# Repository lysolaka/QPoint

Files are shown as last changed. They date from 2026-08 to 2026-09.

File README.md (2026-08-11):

# QPoint

This is a medicore BJT measurement device. It does not use SMUs, negative voltages, and other fancy things. The focus of this project was to learn analog circuits and use them in something (hopefully fun).

# License

This project is licensed under the GNU General Public License v3.0 or later (at your option).

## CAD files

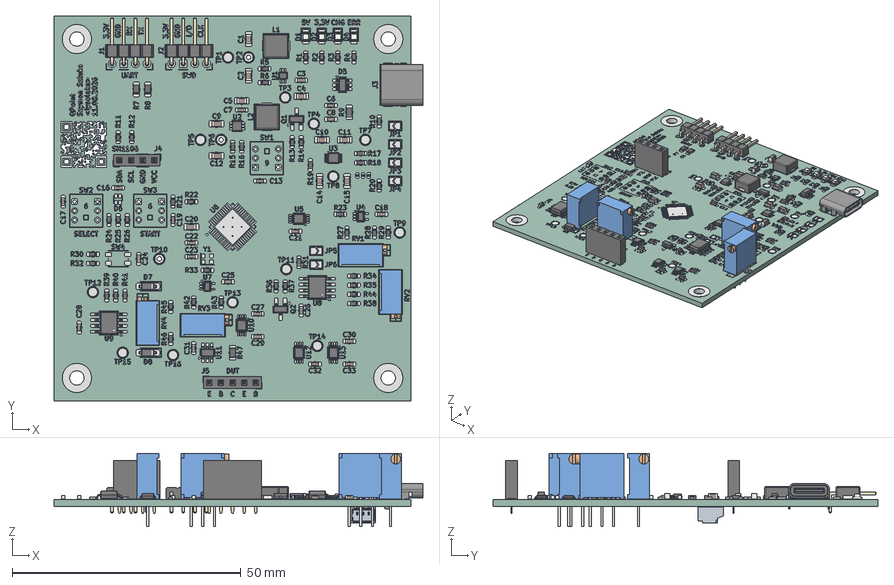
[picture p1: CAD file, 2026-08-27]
QPoint/QPointModel.step
80.6 x 84.0 x 16.1 mm
Potentiometer_Bourns_3296X_Horizontal x 4
R_0603_1608Metric x 43
C_0603_1608Metric x 22
R_0805_2012Metric x 4
USB_C_Receptacle_GCT_USB4085
D_SOD-123 x 2
PinHeader_1x04_P254mm_Horizontal x 2
C_0805_2012Metric x 11
Texas_DLH0010A_WSON-10-1EP_2.2x2mm_P0.4mm_EP0.9x1.5mm
SOT_563
PinSocket_1x05_P2.54mm_Vertical
SOT-353_SC-70-5 x 2
PinSocket_1x04_P2.54mm_Vertical
SOIC-8_3.9x4.9mm_P1.27mm x 2
VSSOP-8_2.3x2mm_P0.5mm x 4
SOT-23-6 x 2
a6ee02de-8551-11ed-a139-00155d22e2d7_part x 2
a6ee040a-8551-11ed-a139-00155d22e2d7_part x 2
a6ee048c-8551-11ed-a139-00155d22e2d7_part x 2
LED_0805_2012Metric x 4
SOT-23 x 2
WSON_6_1EP_2x2mm_P065mm_EP1x16mm
QPoint_pad
QPoint_silkscreen x 2
QPoint_PCB

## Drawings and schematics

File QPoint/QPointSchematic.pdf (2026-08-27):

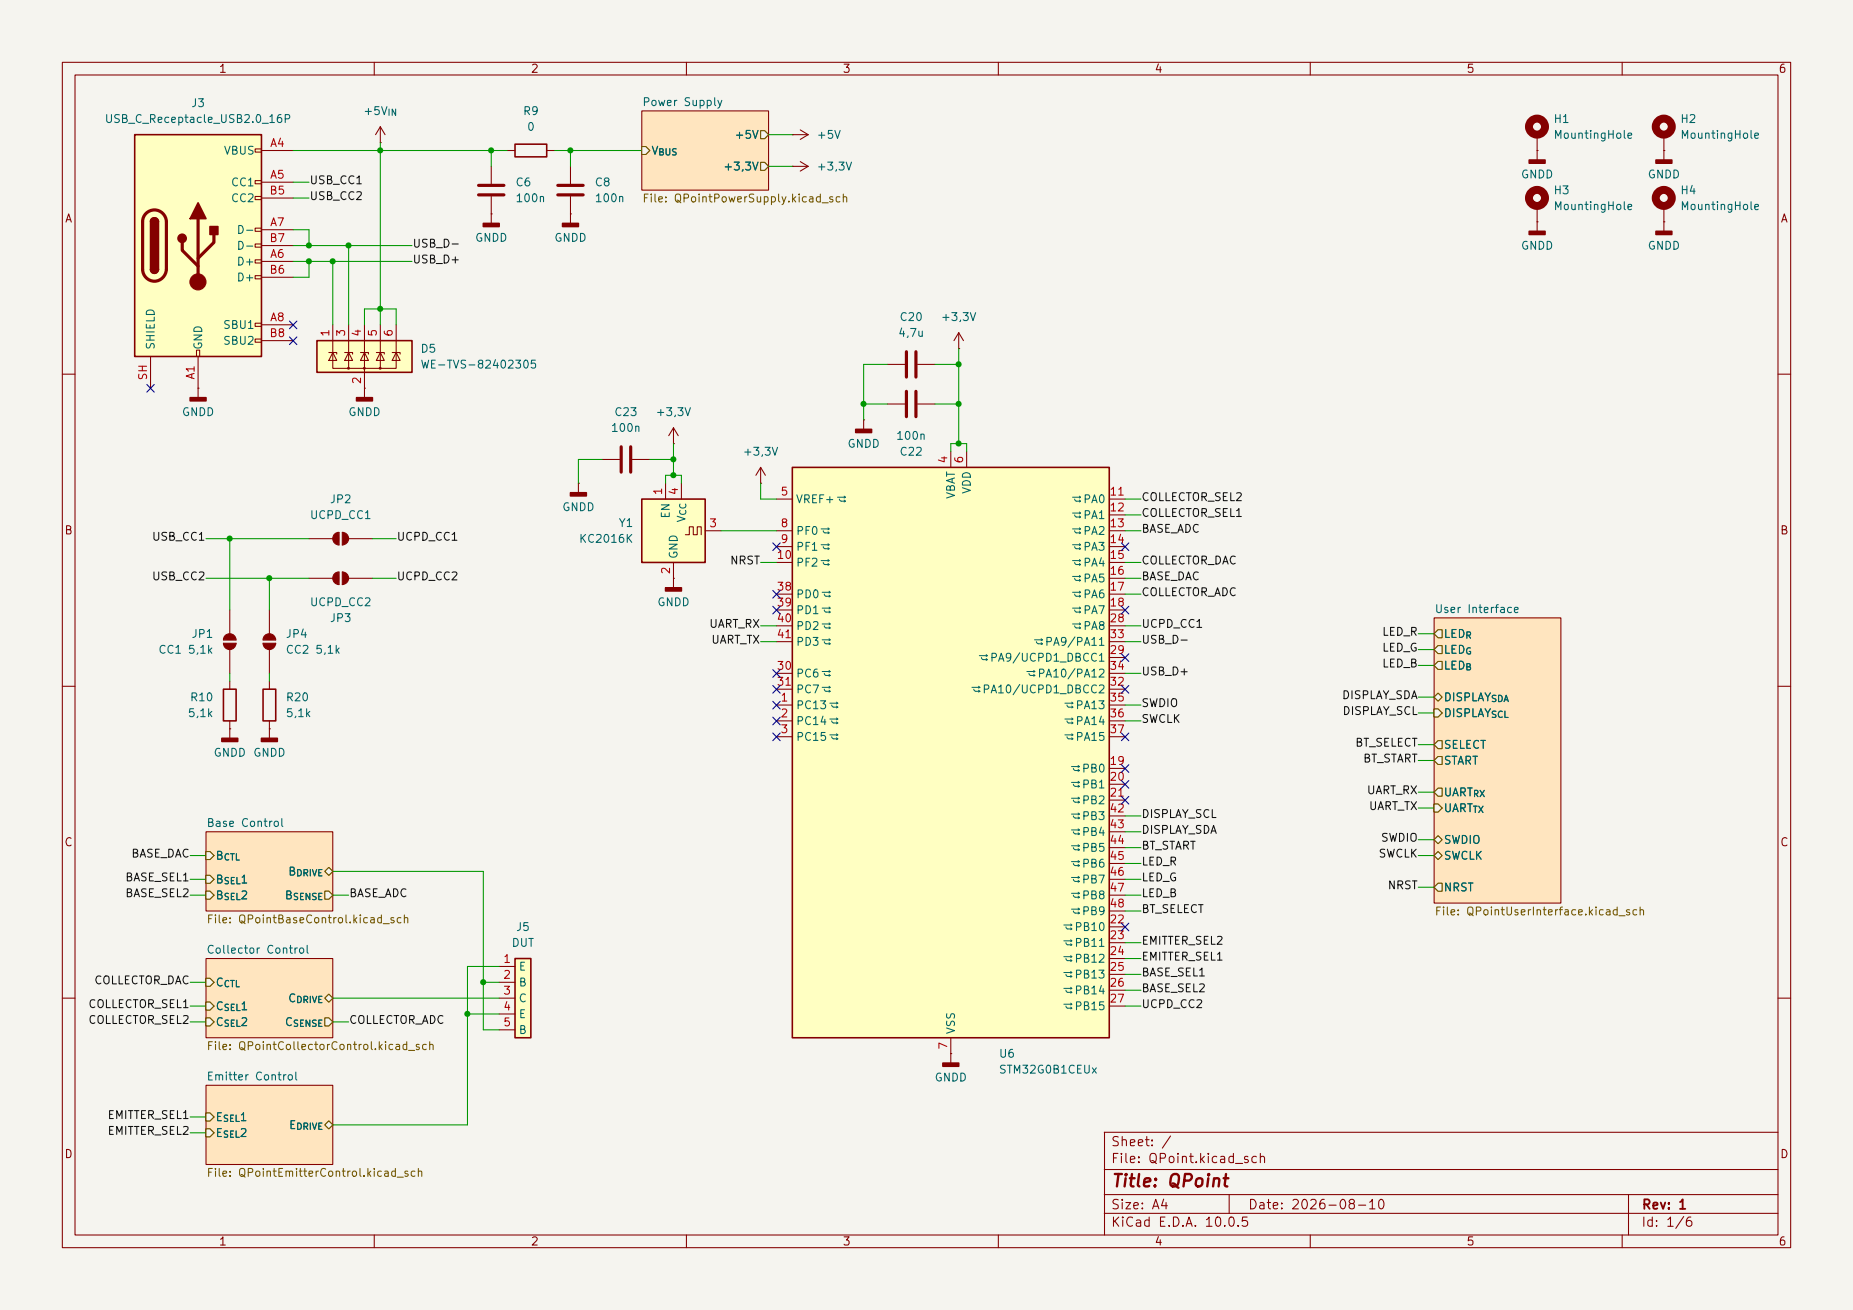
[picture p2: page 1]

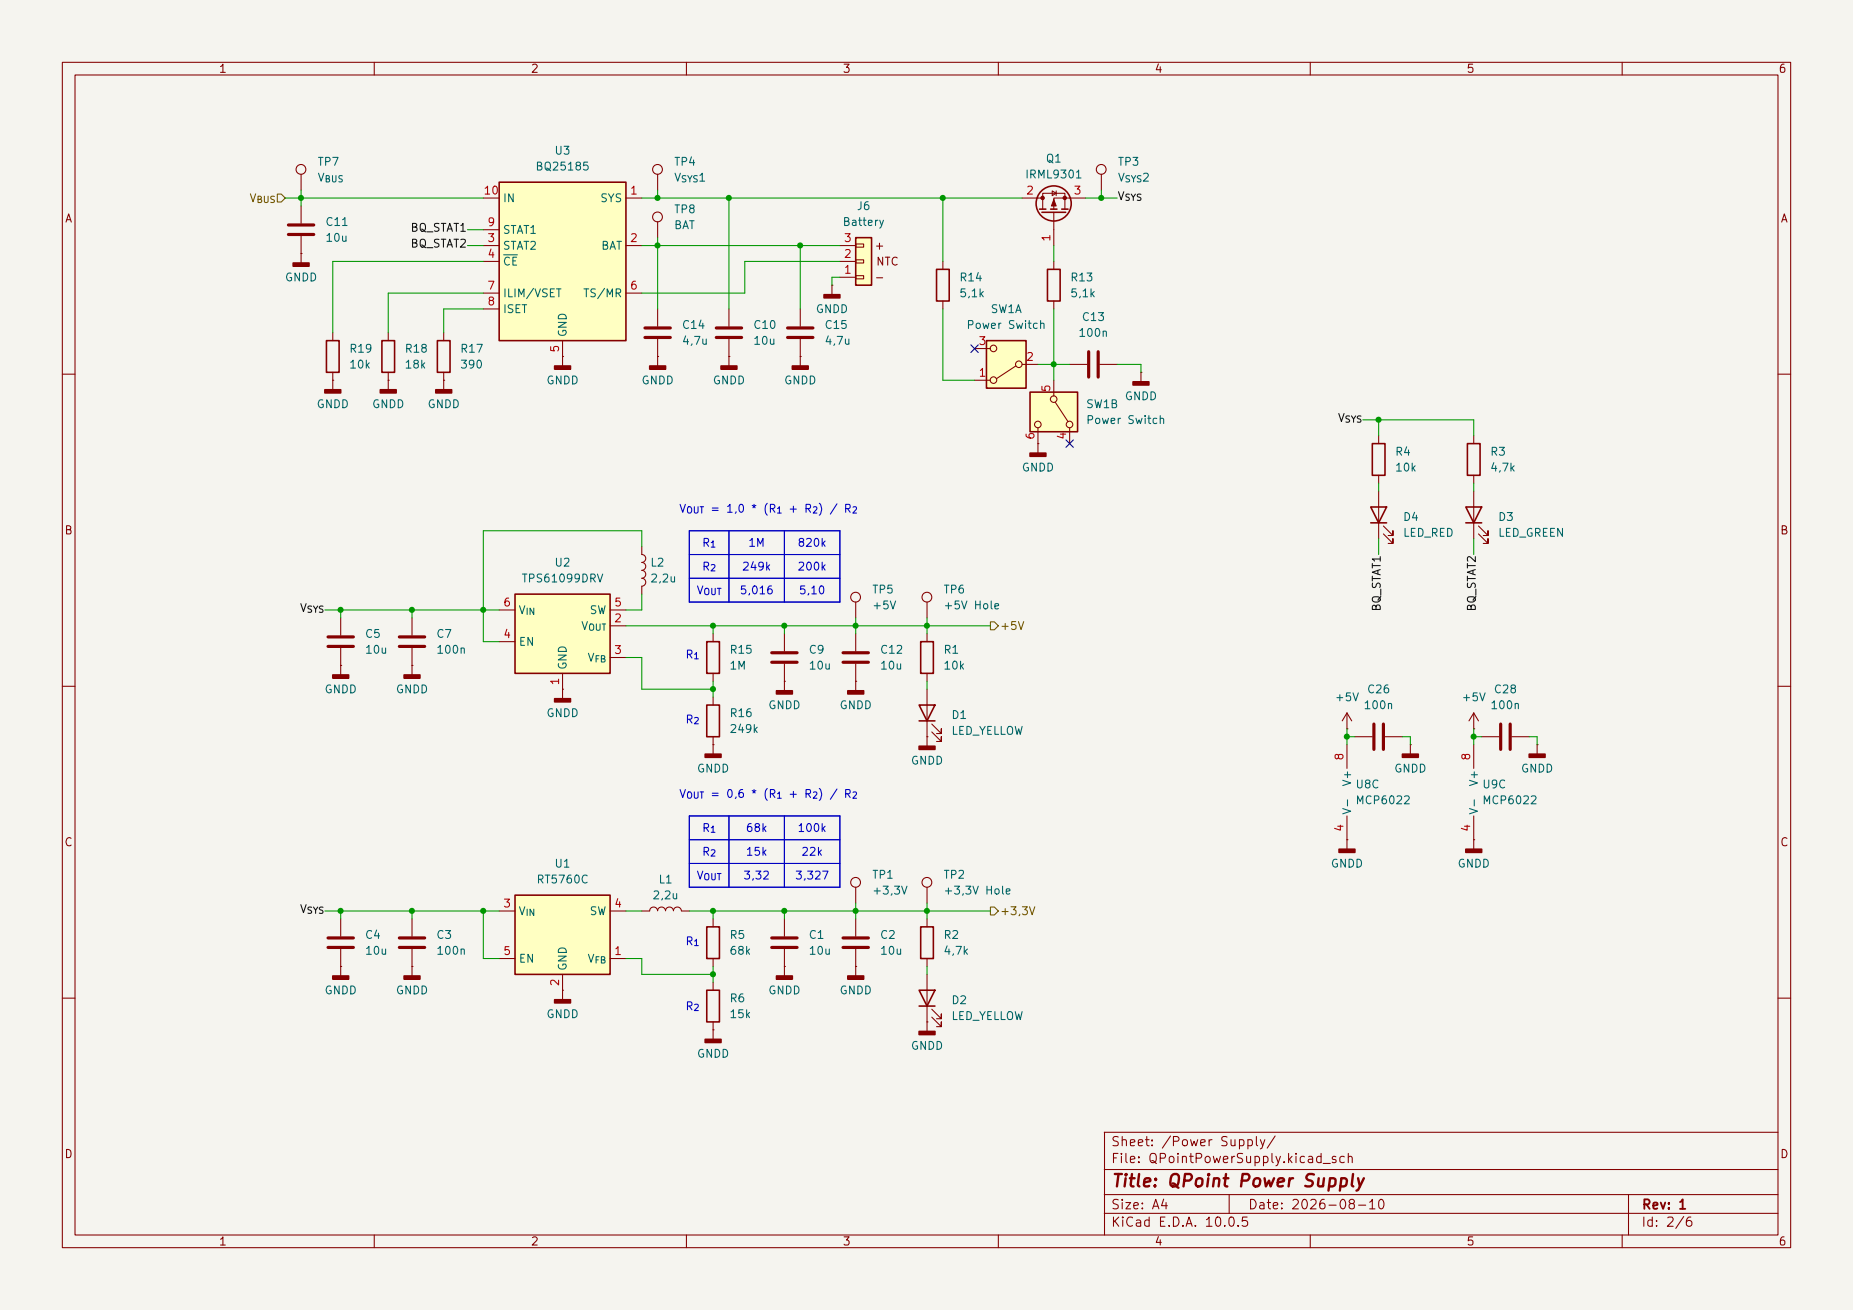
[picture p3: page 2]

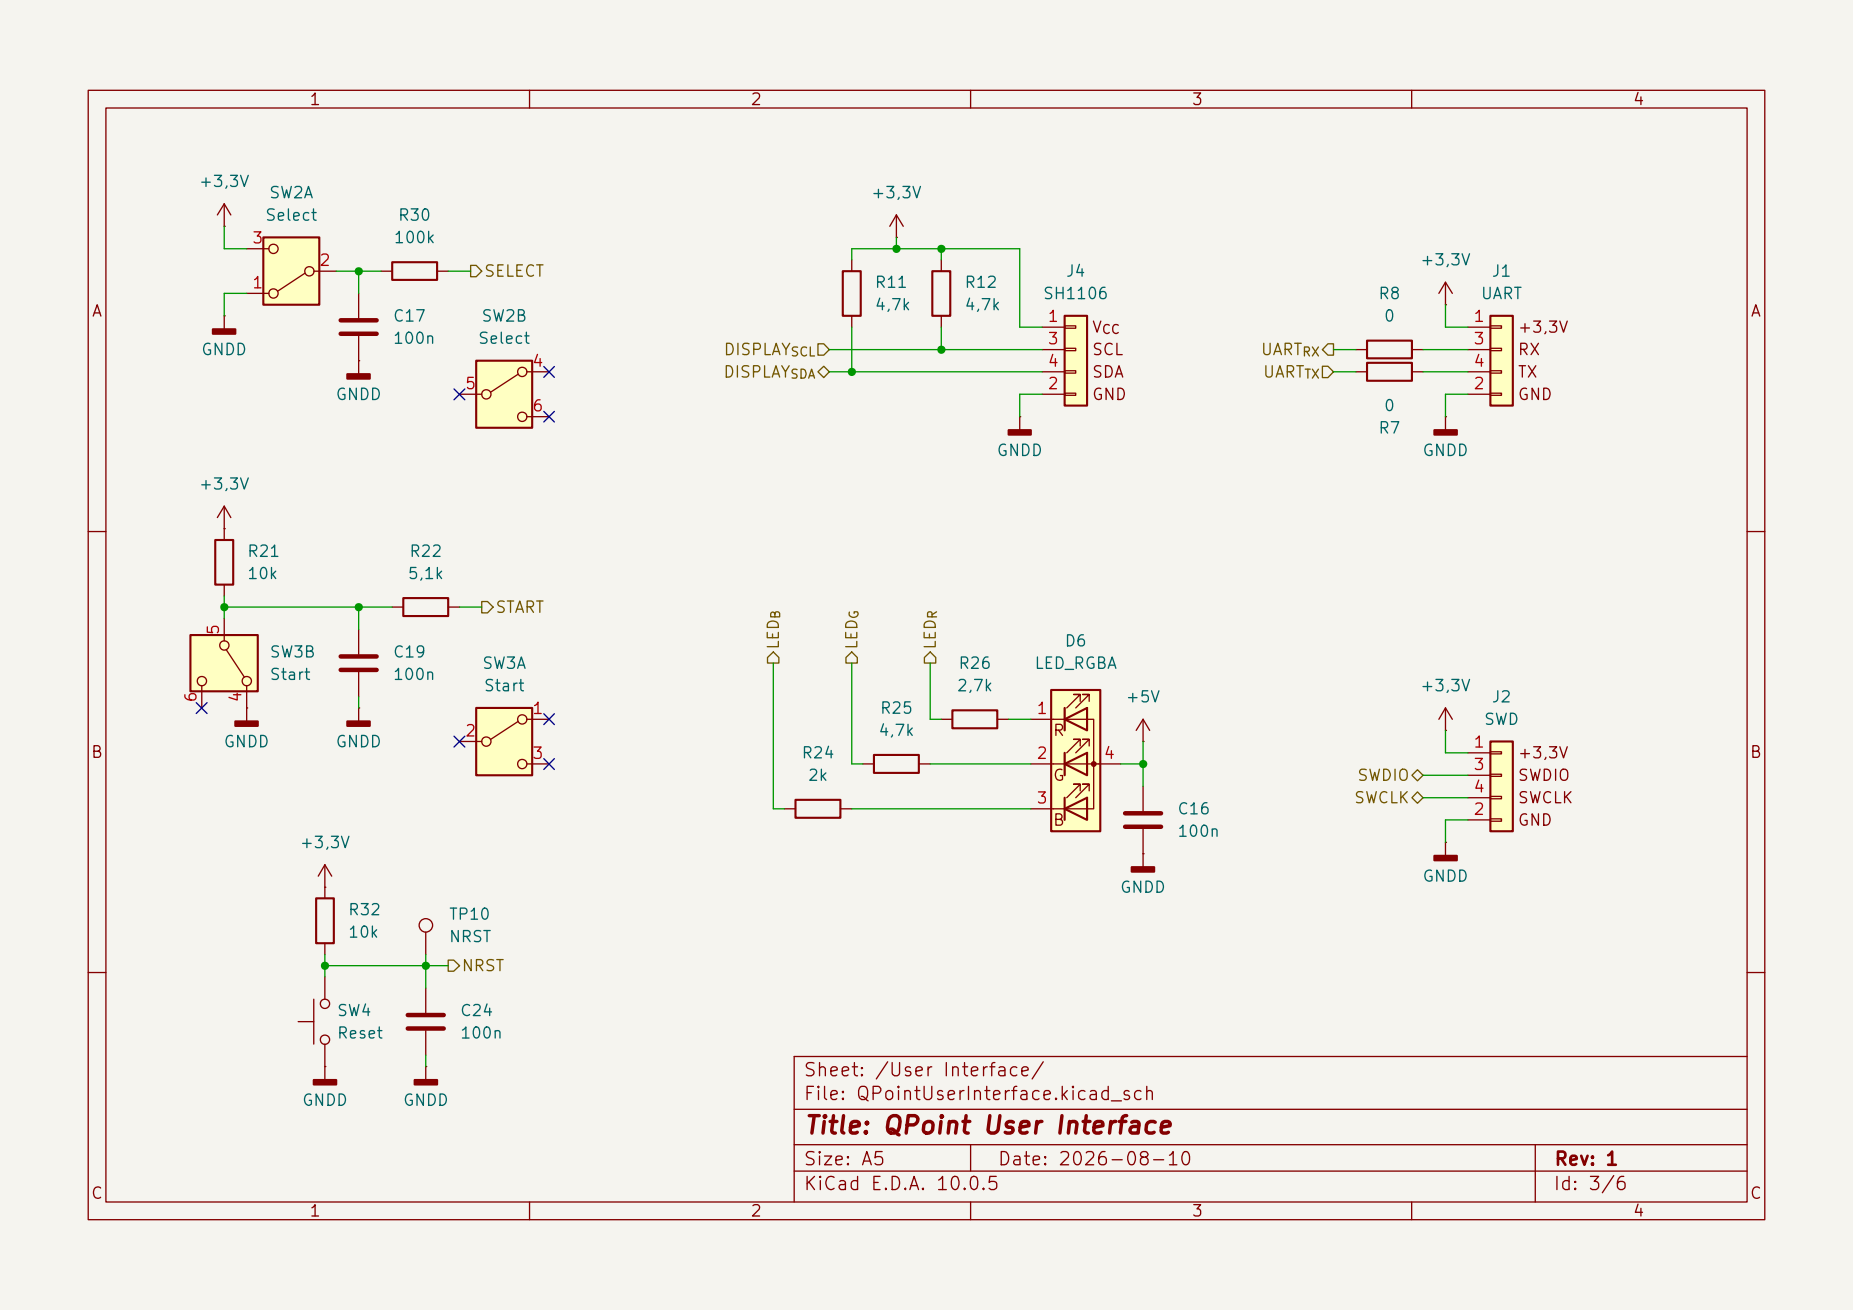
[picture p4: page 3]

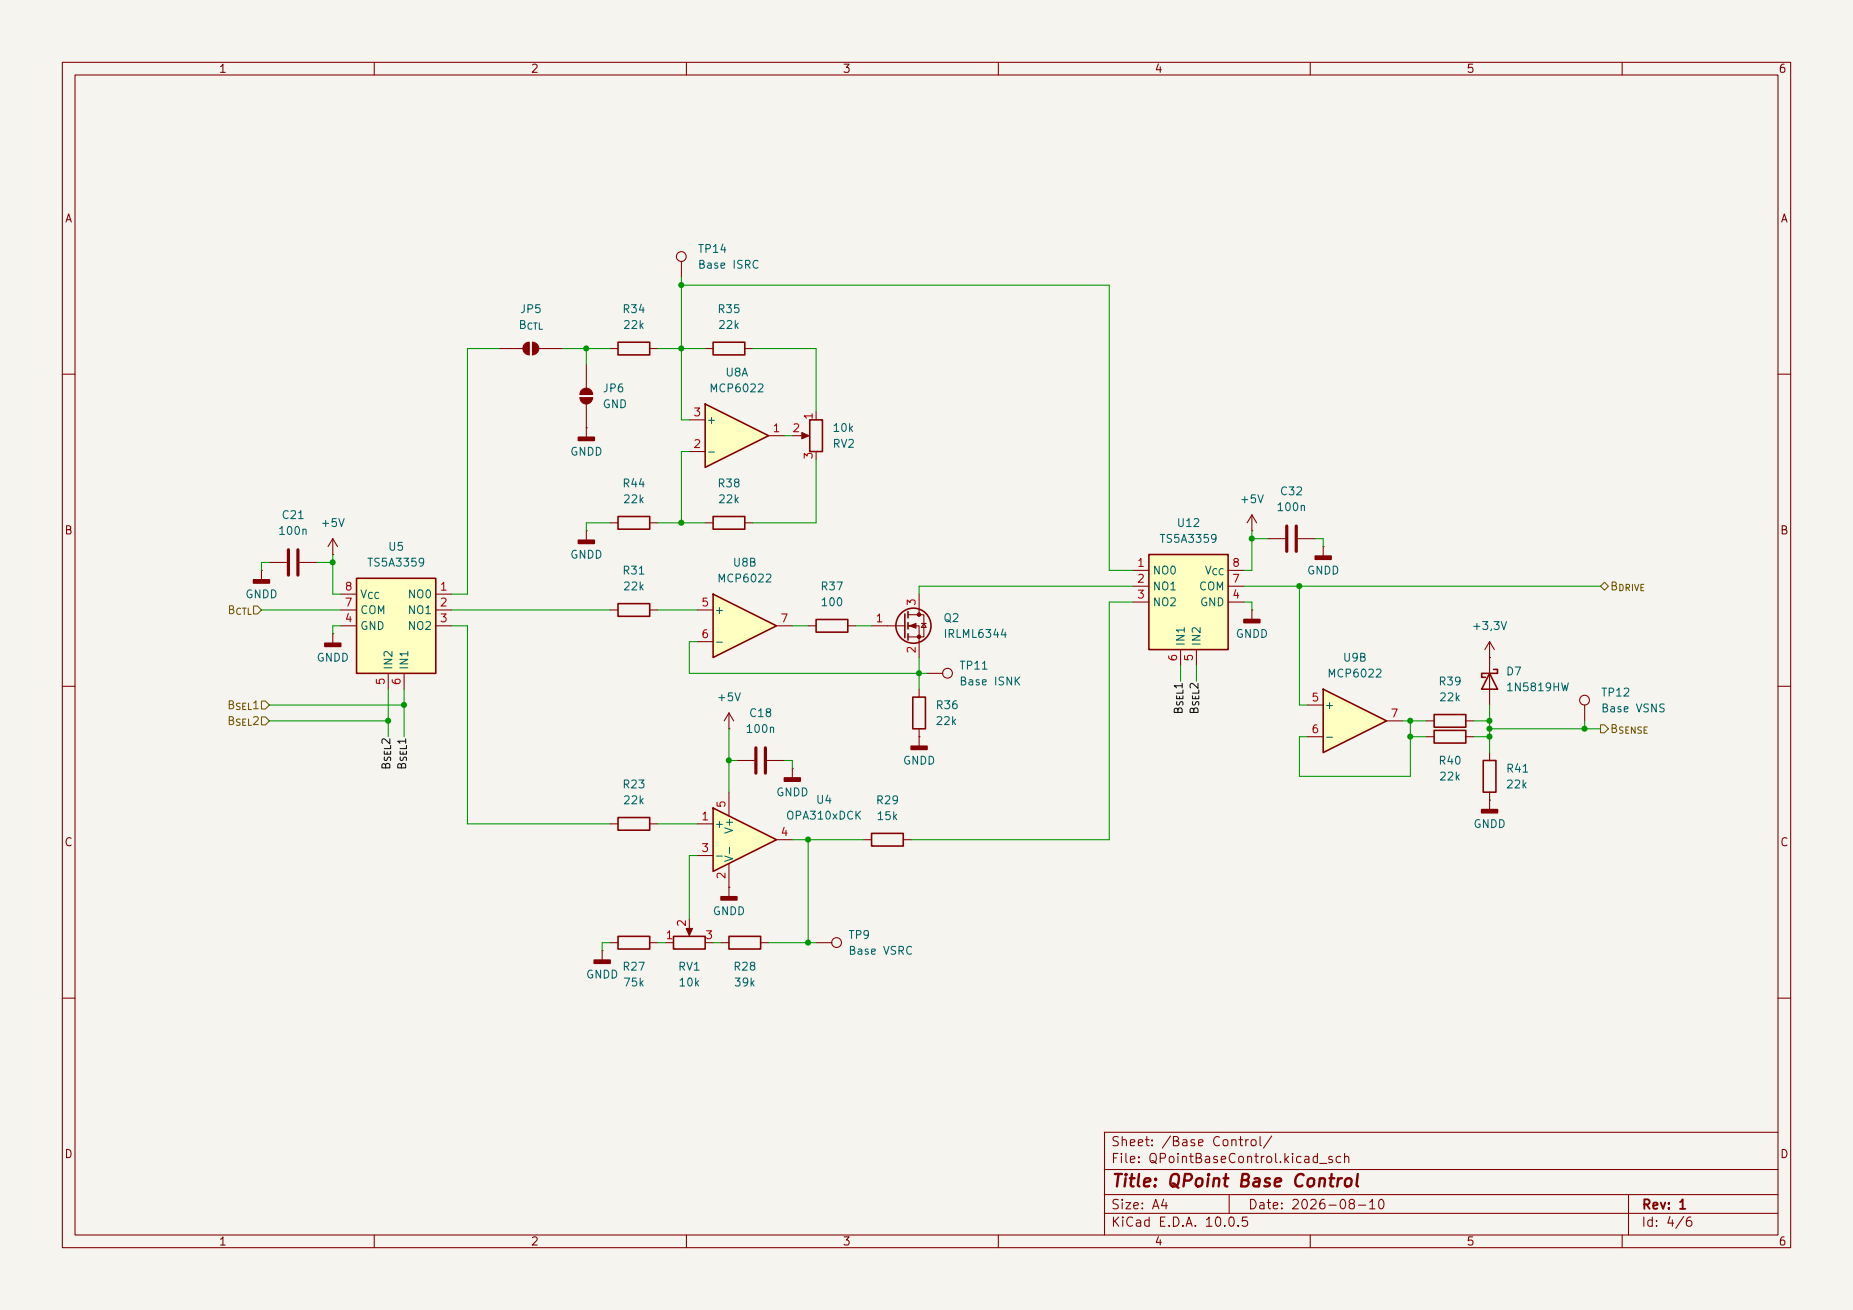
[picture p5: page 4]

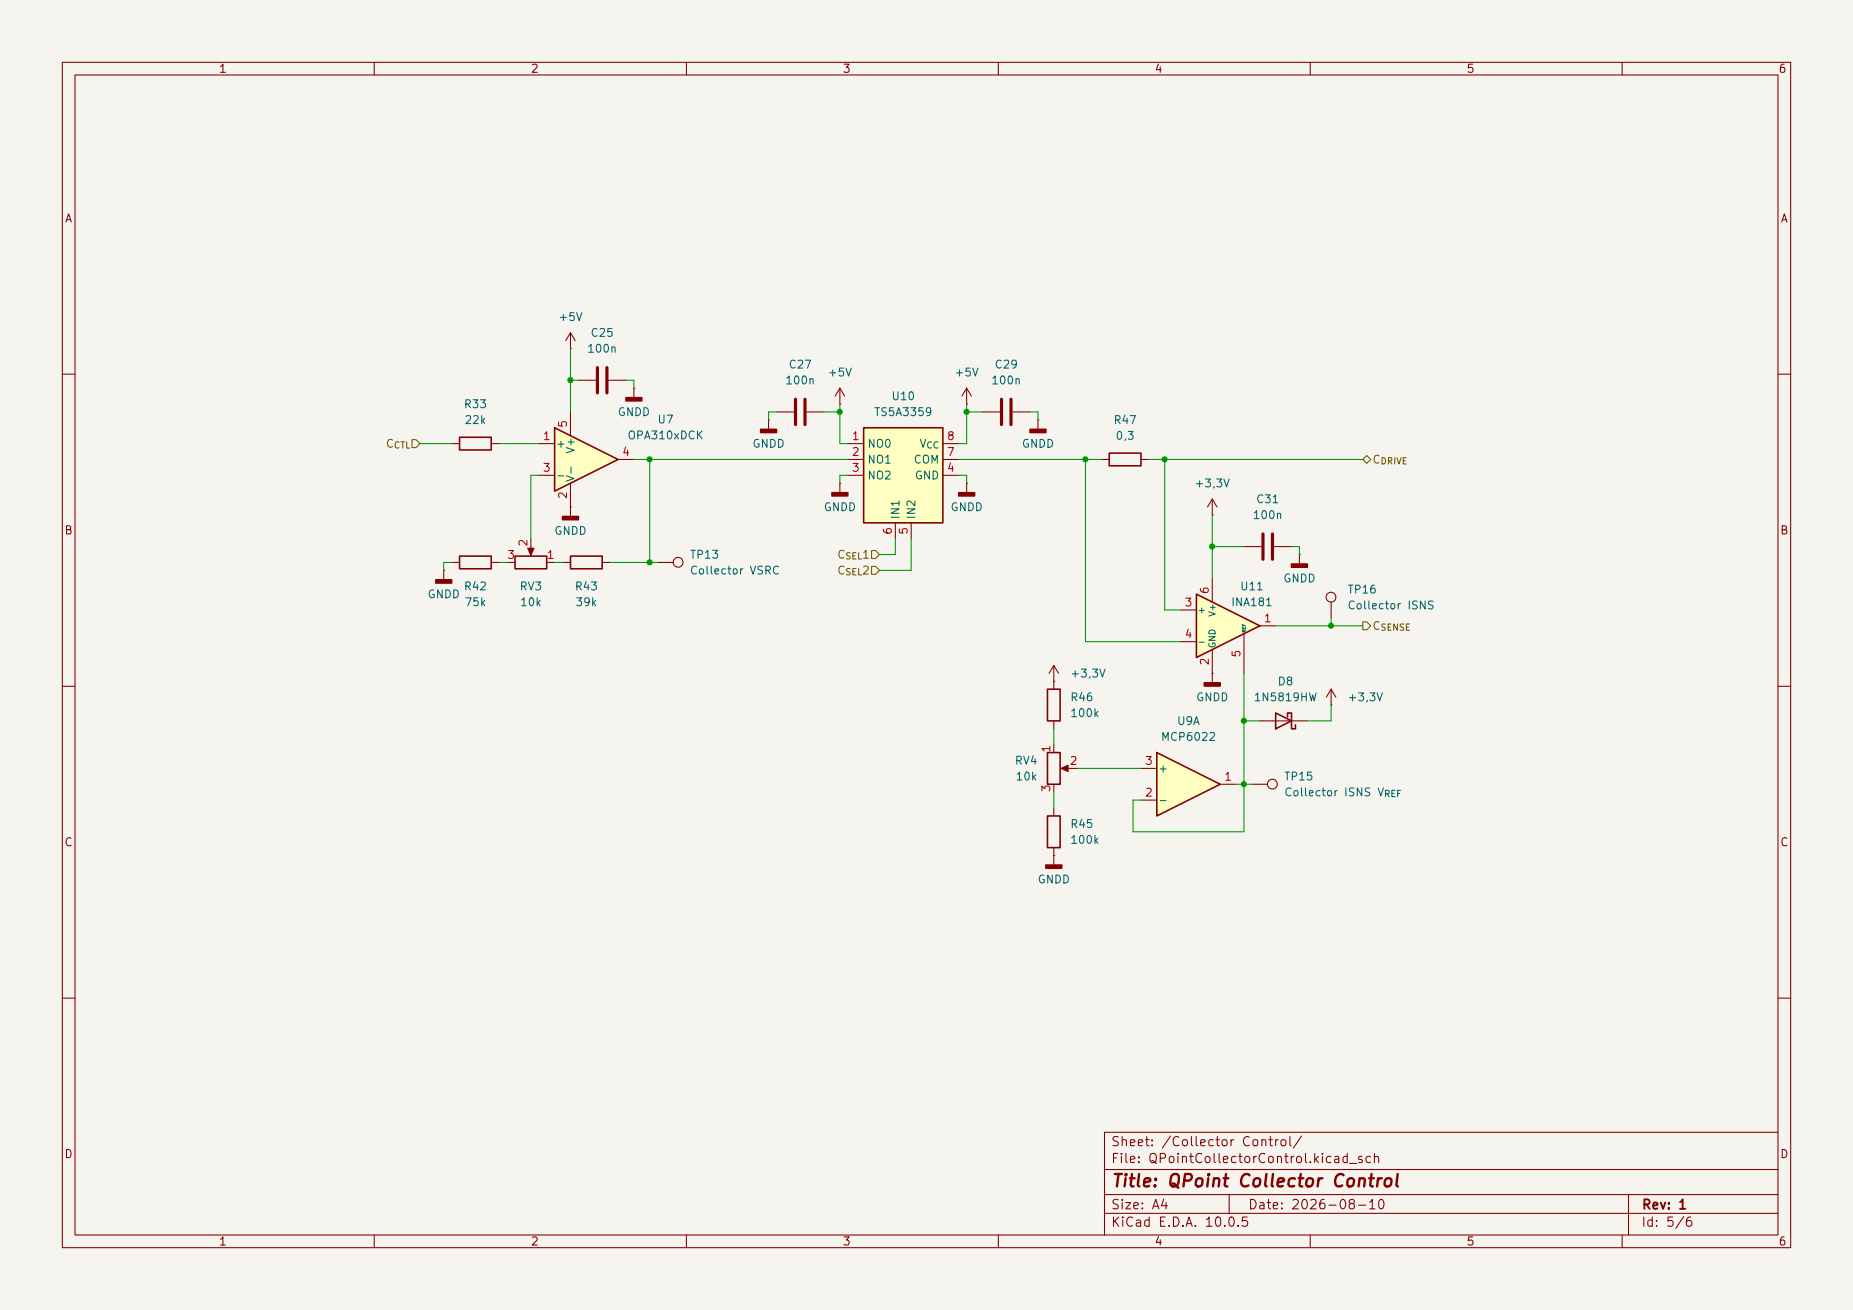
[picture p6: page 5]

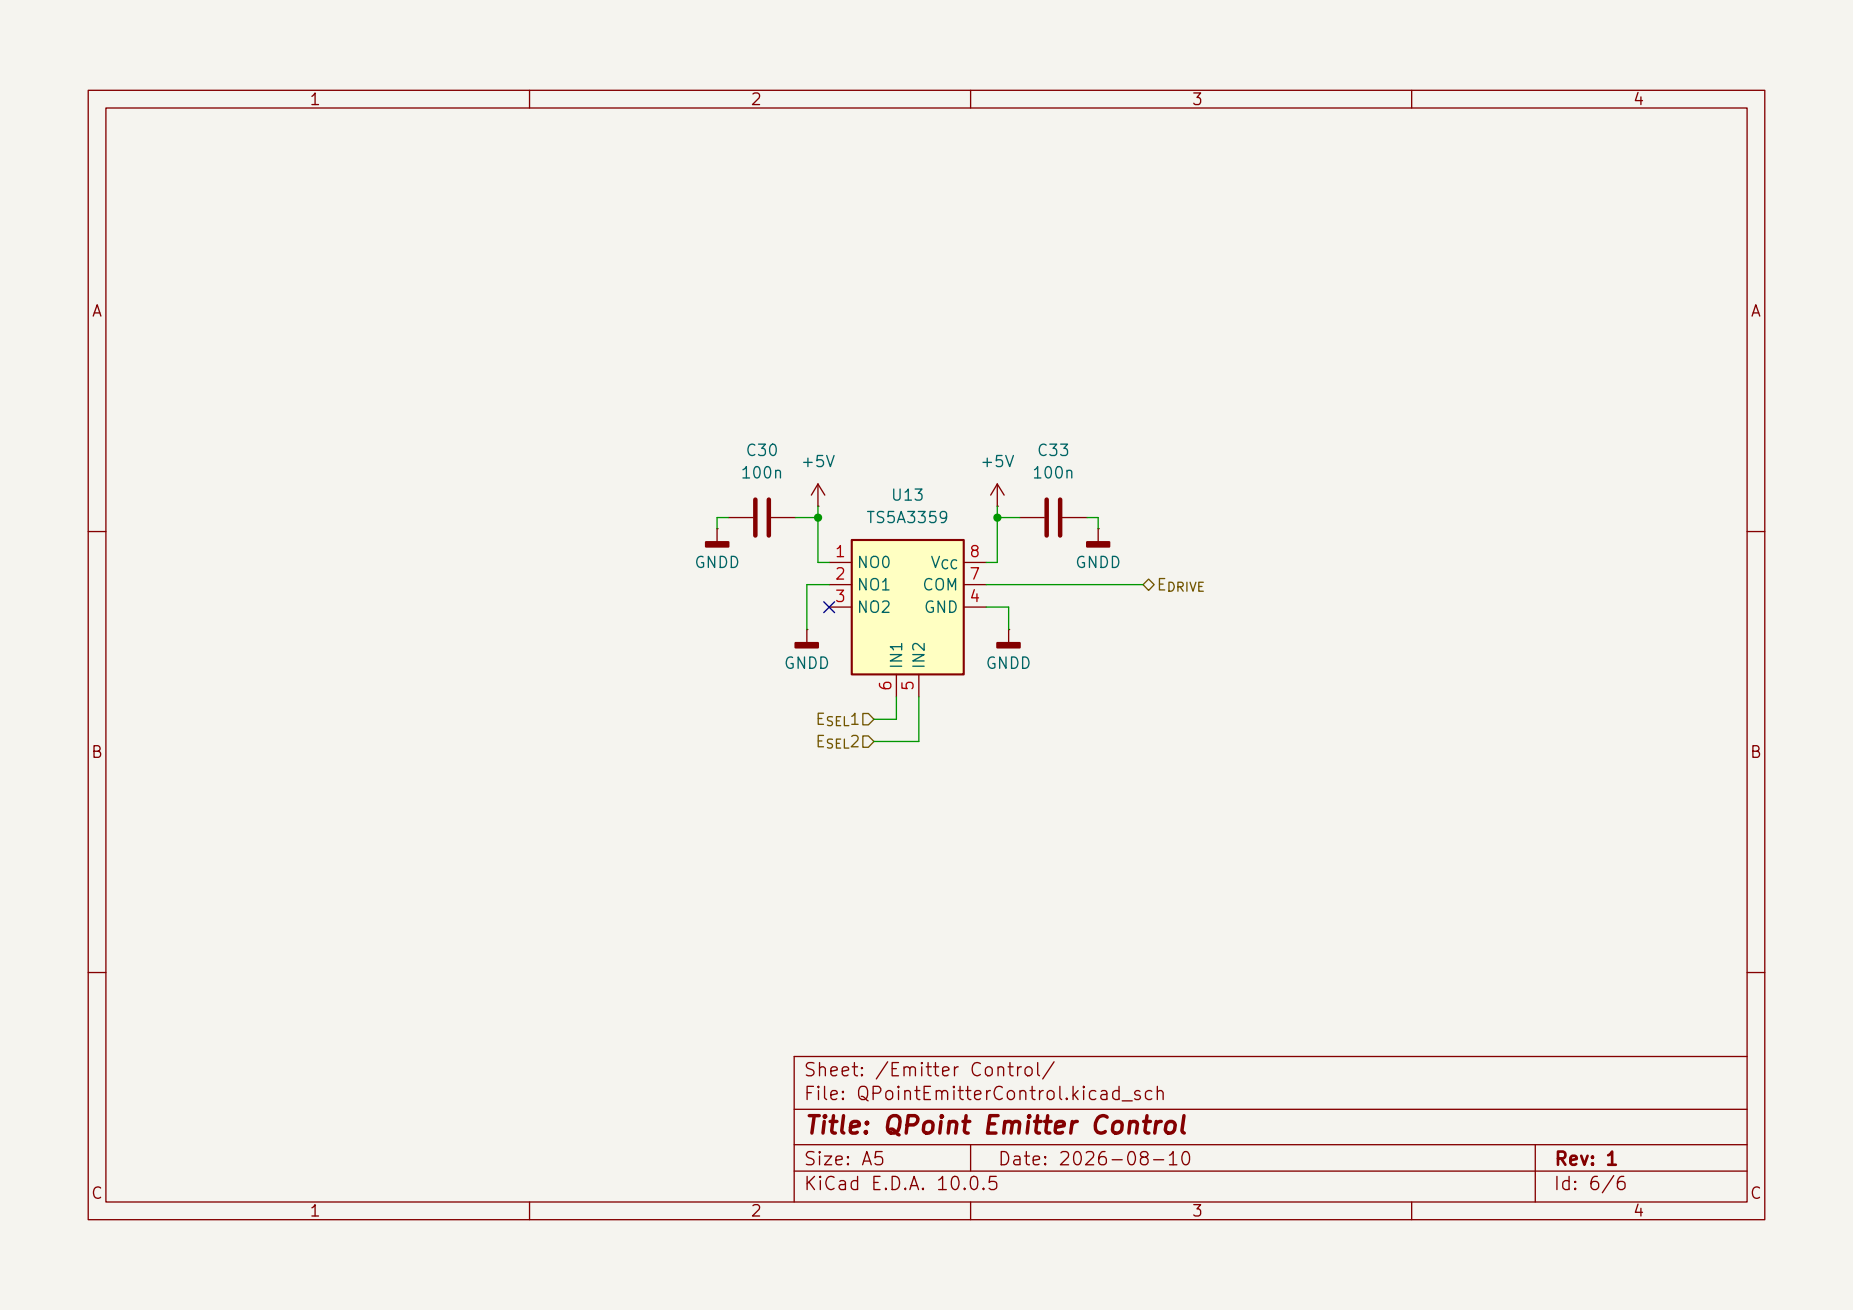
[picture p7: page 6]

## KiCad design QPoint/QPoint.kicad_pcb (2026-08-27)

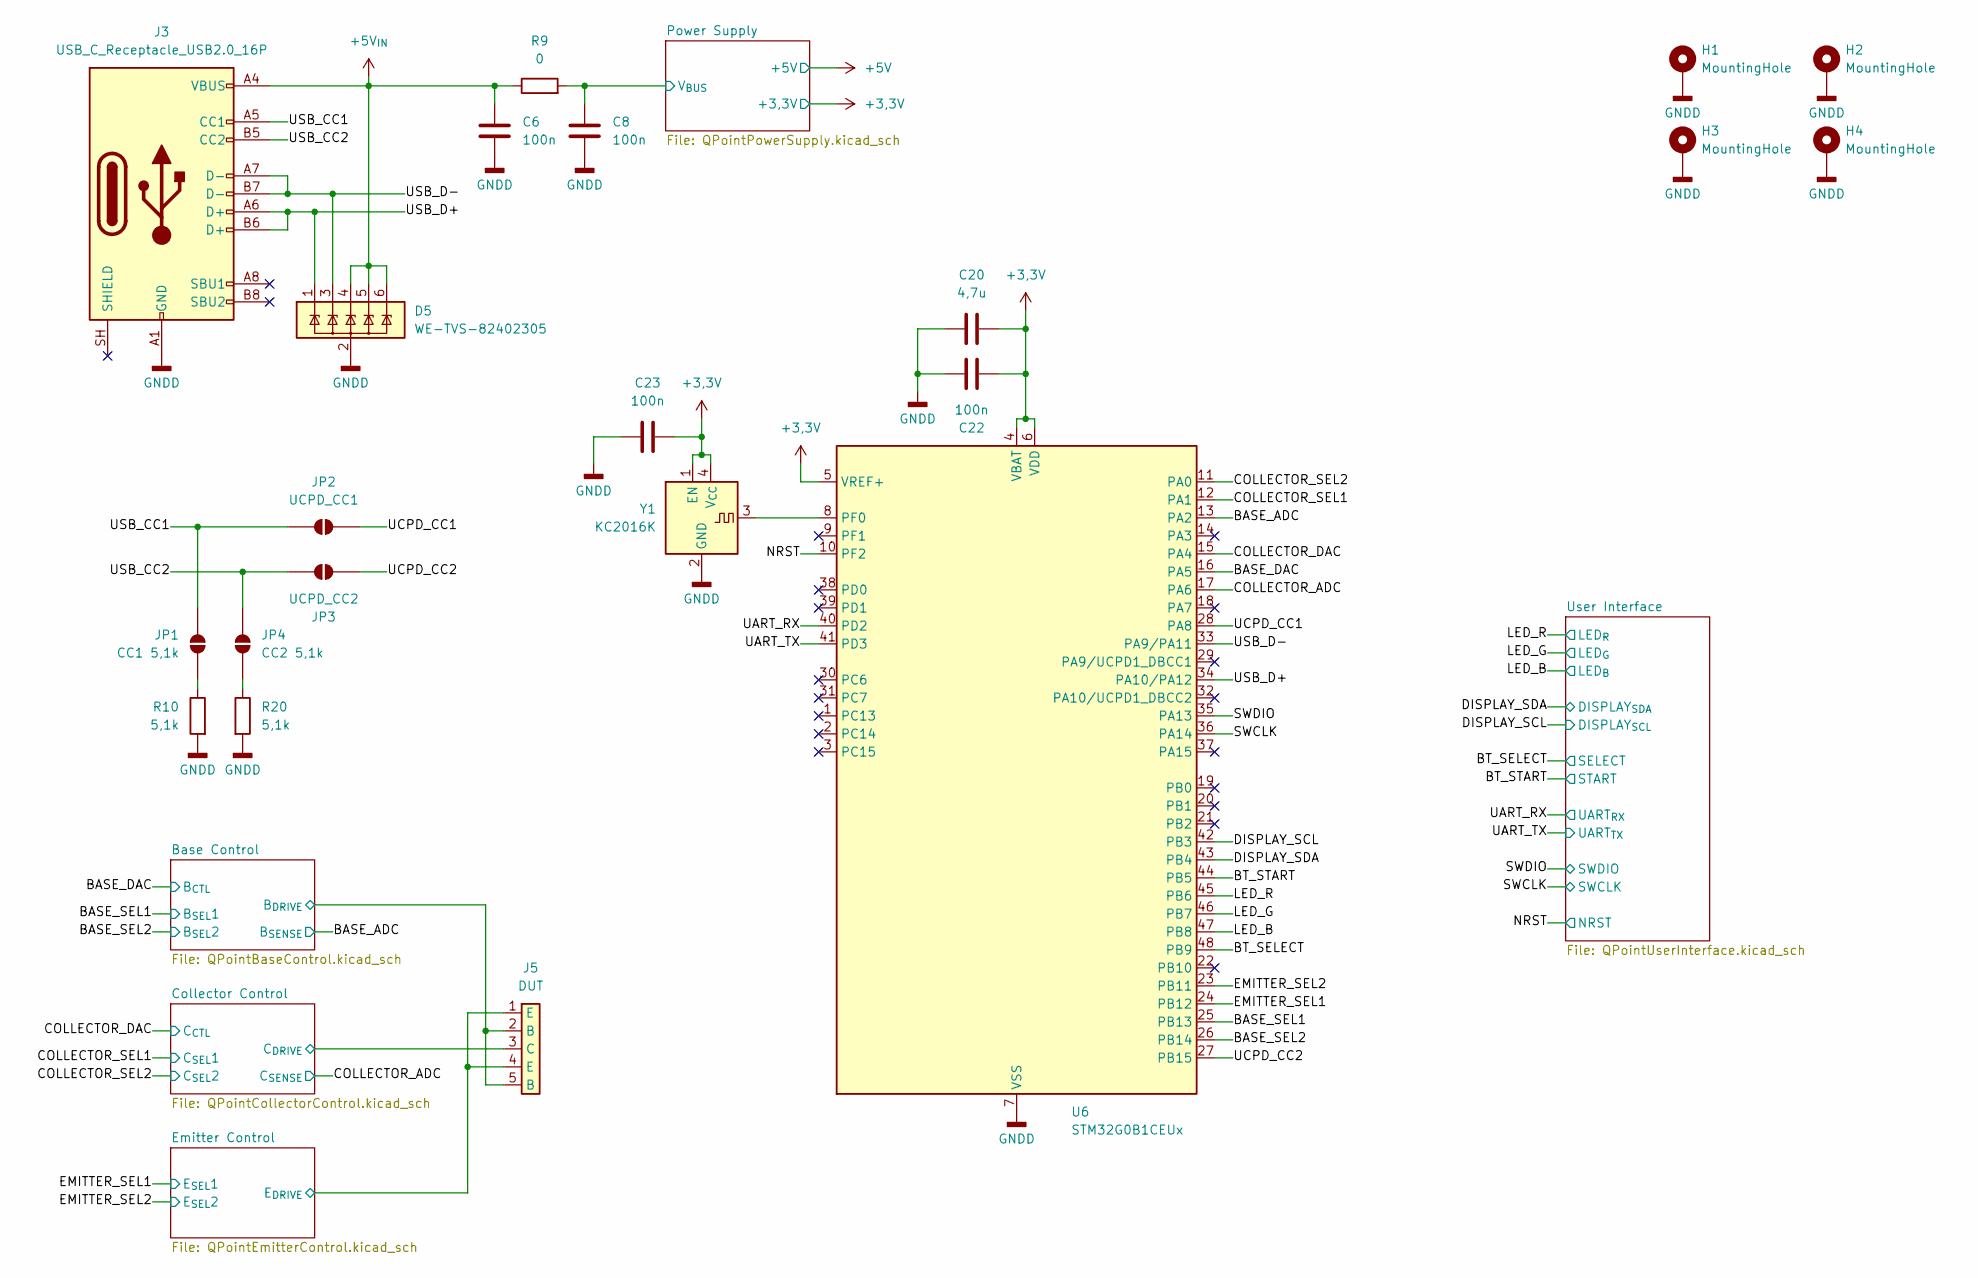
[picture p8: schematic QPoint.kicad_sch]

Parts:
C6, C8, C22, C23: 100n; C_0603_1608Metric_Pad1.08x0.95mm_HandSolder
C20: 4,7u; C_0805_2012Metric_Pad1.18x1.45mm_HandSolder
D5: WE-TVS-82402305; SOT-23-6_Handsoldering
H1, H2, H3, H4: MountingHole; MountingHole_3.2mm_M3_Pad
J3: USB_C_Receptacle_USB2.0_16P; USB_C_Receptacle_GCT_USB4085
J5: DUT; Connector_DUT_P2.54mm
JP1: CC1 5,1k; SolderJumper-2_P1.3mm_Open_TrianglePad1.0x1.5mm
JP2: UCPD_CC1; SolderJumper-2_P1.3mm_Open_TrianglePad1.0x1.5mm
JP3: UCPD_CC2; SolderJumper-2_P1.3mm_Open_TrianglePad1.0x1.5mm
JP4: CC2 5,1k; SolderJumper-2_P1.3mm_Open_TrianglePad1.0x1.5mm
R9: 0; R_0805_2012Metric_Pad1.20x1.40mm_HandSolder
R10, R20: 5,1k; R_0603_1608Metric_Pad0.98x0.95mm_HandSolder
U6: STM32G0B1CEUx; QFN-48-1EP_7x7mm_P0.5mm_EP5.6x5.6mm_GroundingVias
Y1: KC2016K; Oscillator_SMD_KC2016K_2.0x.16mm

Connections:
+3,3V: C20.2, C22.2, C23.2, U6.4 (VBAT), U6.5 (VREF+), U6.6 (VDD), Y1.1 (EN), Y1.4 (V_{CC}); also elsewhere on the board
+5V_{IN}: C6.1, D5.4, D5.5, D5.6, J3.A4 (VBUS), J3.A9 (VBUS), J3.B4 (VBUS), J3.B9 (VBUS), R9.1
/BASE_ADC: U6.13 (PA2); also elsewhere on the board
/BASE_DAC: U6.16 (PA5); also elsewhere on the board
/BASE_SEL1: U6.25 (PB13); also elsewhere on the board
/BASE_SEL2: U6.26 (PB14); also elsewhere on the board
/BT_SELECT: U6.48 (PB9); also elsewhere on the board
/BT_START: U6.44 (PB5); also elsewhere on the board
/Base Control/B_{DRIVE}: J5.2 (B), J5.5 (B); also elsewhere on the board
/COLLECTOR_ADC: U6.17 (PA6); also elsewhere on the board
/COLLECTOR_DAC: U6.15 (PA4); also elsewhere on the board
/COLLECTOR_SEL1: U6.12 (PA1); also elsewhere on the board
/COLLECTOR_SEL2: U6.11 (PA0); also elsewhere on the board
/Collector Control/C_{DRIVE}: J5.3 (C); also elsewhere on the board
/DISPLAY_SCL: U6.42 (PB3); also elsewhere on the board
/DISPLAY_SDA: U6.43 (PB4); also elsewhere on the board
/EMITTER_SEL1: U6.24 (PB12); also elsewhere on the board
/EMITTER_SEL2: U6.23 (PB11); also elsewhere on the board
/Emitter Control/E_{DRIVE}: J5.1 (E), J5.4 (E); also elsewhere on the board
/LED_B: U6.47 (PB8); also elsewhere on the board
/LED_G: U6.46 (PB7); also elsewhere on the board
/LED_R: U6.45 (PB6); also elsewhere on the board
/NRST: U6.10 (PF2); also elsewhere on the board
/Power Supply/V_{BUS}: C8.1, R9.2; also elsewhere on the board
/SWCLK: U6.36 (PA14); also elsewhere on the board
/SWDIO: U6.35 (PA13); also elsewhere on the board
/UART_RX: U6.40 (PD2); also elsewhere on the board
/UART_TX: U6.41 (PD3); also elsewhere on the board
/UCPD_CC1: JP2.2 (B), U6.28 (PA8)
/UCPD_CC2: JP3.2 (B), U6.27 (PB15)
/USB_CC1: J3.A5 (CC1), JP1.1 (A), JP2.1 (A)
/USB_CC2: J3.B5 (CC2), JP3.1 (A), JP4.1 (A)
/USB_D+: D5.1, J3.A6 (D+), J3.B6 (D+), U6.34 (PA10/PA12)
/USB_D-: D5.3, J3.A7 (D-), J3.B7 (D-), U6.33 (PA9/PA11)
GNDD: C6.2, C8.2, C20.1, C22.1, C23.1, D5.2, H1.1 (1_1), H2.1 (1_1), H3.1 (1_1), H4.1 (1_1), J3.A1 (GND), J3.A12 (GND), J3.B1 (GND), J3.B12 (GND), R10.2, R20.2, U6.7 (VSS), U6.49 (VSS), Y1.2 (GND); also elsewhere on the board
unnamed: JP1.2 (B), R10.1
unnamed: JP4.2 (B), R20.1
unnamed: U6.8 (PF0), Y1.3

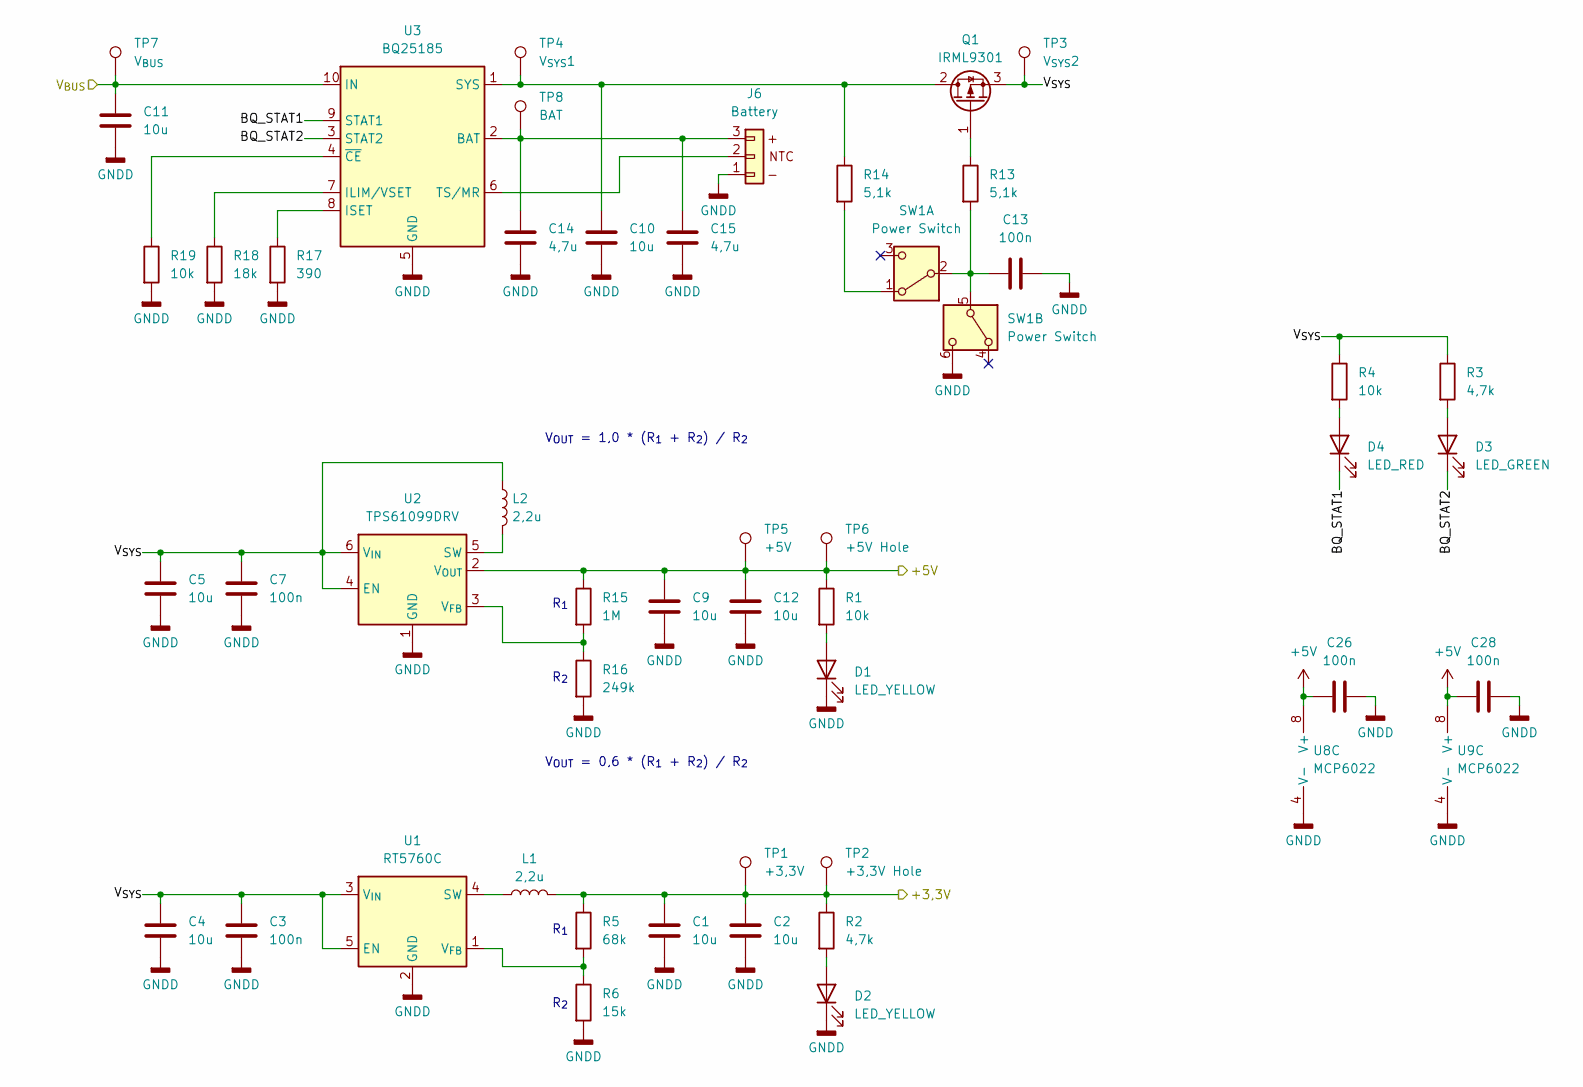
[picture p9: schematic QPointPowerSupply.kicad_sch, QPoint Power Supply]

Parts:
C1, C2, C4, C5, C9, C10, C11, C12: 10u; C_0805_2012Metric_Pad1.18x1.45mm_HandSolder
C3, C7, C13, C26, C28: 100n; C_0603_1608Metric_Pad1.08x0.95mm_HandSolder
C14, C15: 4,7u; C_0805_2012Metric_Pad1.18x1.45mm_HandSolder
D1, D2: LED_YELLOW; LED_0805_2012Metric_Pad1.15x1.40mm_HandSolder
D3: LED_GREEN; LED_0805_2012Metric_Pad1.15x1.40mm_HandSolder
D4: LED_RED; LED_0805_2012Metric_Pad1.15x1.40mm_HandSolder
J6: Battery; Molex_PicoBlade_53048-0310_1x03_P1.25mm_Horizontal
L1, L2: 2,2u; L_Sunlord_MWSA0503S
Q1: IRML9301; SOT-23_Handsoldering
R1, R4, R19: 10k; R_0603_1608Metric_Pad0.98x0.95mm_HandSolder
R2, R3: 4,7k; R_0603_1608Metric_Pad0.98x0.95mm_HandSolder
R5: 68k; R_0603_1608Metric_Pad0.98x0.95mm_HandSolder
R6: 15k; R_0603_1608Metric_Pad0.98x0.95mm_HandSolder
R13, R14: 5,1k; R_0603_1608Metric_Pad0.98x0.95mm_HandSolder
R15: 1M; R_0603_1608Metric_Pad0.98x0.95mm_HandSolder
R16: 249k; R_0603_1608Metric_Pad0.98x0.95mm_HandSolder
R17: 390; R_0603_1608Metric_Pad0.98x0.95mm_HandSolder
R18: 18k; R_0603_1608Metric_Pad0.98x0.95mm_HandSolder
SW1: Power Switch; SW_Push_PB07_7x7mm
TP1: +3,3V; TestPoint_Pad_D2.0mm
TP2: +3,3V Hole; TestPoint_THTPad_D2.0mm_Drill1.0mm
TP3: V_{SYS}2; TestPoint_Pad_D2.0mm
TP4: V_{SYS}1; TestPoint_Pad_D2.0mm
TP5: +5V; TestPoint_Pad_D2.0mm
TP6: +5V Hole; TestPoint_THTPad_D2.0mm_Drill1.0mm
TP7: V_{BUS}; TestPoint_Pad_D2.0mm
TP8: BAT; TestPoint_Pad_D2.0mm
U1: RT5760C; SOT-563_Handsoldering
U2: TPS61099DRV; WSON-6-1EP_2x2mm_P0.65mm_EP1x1.6mm_GroundingVias
U3: BQ25185; Texas_DLH0010A_WSON-10-1EP_2.2x2mm_P0.4mm_EP0.9x1.5mm_Groun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
U8, U9: MCP6022; SOIC-8_3.9x4.9mm_P1.27mm_Handsoldering

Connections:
+3,3V: C1.1, C2.1, L1.2, R2.1, R5.1, TP1.1 (1_1), TP2.1 (1_1); also elsewhere on the board
+5V: C9.1, C12.1, C26.1, C28.1, R1.1, R15.1, TP5.1 (1_1), TP6.1 (1_1), U2.2 (V_{OUT}), U8.8 (V+), U9.8 (V+); also elsewhere on the board
/Power Supply/BQ_STAT1: D4.1 (K), U3.9 (STAT1)
/Power Supply/BQ_STAT2: D3.1 (K), U3.3 (STAT2)
/Power Supply/V_{BUS}: C11.1, TP7.1 (1_1), U3.10 (IN); also elsewhere on the board
/Power Supply/V_{SYS}: C3.1, C4.1, C5.1, C7.1, L2.1, Q1.3 (S), R3.1, R4.1, TP3.1 (1_1), U1.3 (V_{IN}), U1.5 (EN), U2.4 (EN), U2.6 (V_{IN})
GNDD: C1.2, C2.2, C3.2, C4.2, C5.2, C7.2, C9.2, C10.2, C11.2, C12.2, C13.2, C14.2, C15.2, C26.2, C28.2, D1.1 (K), D2.1 (K), J6.1, R6.2, R16.2, R17.2, R18.2, R19.2, SW1.6 (C), U1.2 (GND), U2.1 (GND), U2.7 (GND), U3.5 (GND), U3.11 (TP), U8.4 (V-), U9.4 (V-); also elsewhere on the board
unnamed: D1.2 (A), R1.2
unnamed: D2.2 (A), R2.2
unnamed: D3.2 (A), R3.2
unnamed: D4.2 (A), R4.2
unnamed: C10.1, Q1.2 (D), R14.1, TP4.1 (1_1), U3.1 (SYS)
unnamed: Q1.1 (G), R13.1
unnamed: R14.2, SW1.1 (A)
unnamed: C13.1, R13.2, SW1.2 (B), SW1.5 (B)
unnamed: L1.1, U1.4 (SW)
unnamed: R5.2, R6.1, U1.1 (V_{FB})
unnamed: L2.2, U2.5 (SW)
unnamed: R15.2, R16.1, U2.3 (V_{FB})
unnamed: C14.1, C15.1, J6.3, TP8.1 (1_1), U3.2 (BAT)
unnamed: R18.1, U3.7 (ILIM/VSET)
unnamed: R17.1, U3.8 (ISET)
unnamed: J6.2, U3.6 (TS/MR)
unnamed: R19.1, U3.4 (~CE)

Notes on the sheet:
R_{2}
V_{OUT} = 0,6 * (R_{1} + R_{2}) / R_{2}
R_{1}
V_{OUT} = 1,0 * (R_{1} + R_{2}) / R_{2}

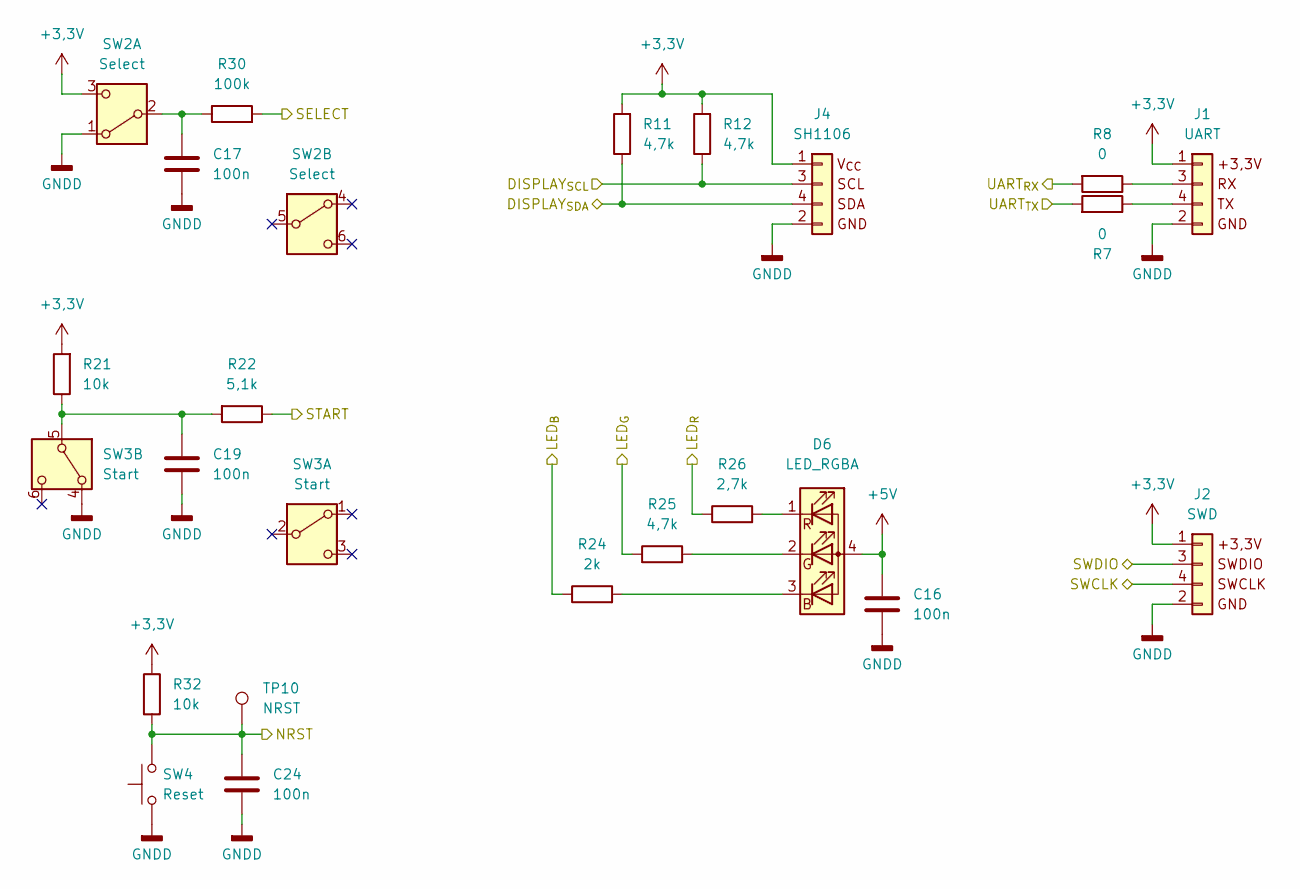
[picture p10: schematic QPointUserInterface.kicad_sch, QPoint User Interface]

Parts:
C16, C17, C19, C24: 100n; C_0603_1608Metric_Pad1.08x0.95mm_HandSolder
D6: LED_RGBA; LED_LiteOn_LTST-C19HE1WT
J1: UART; Connector_UART_P2.54mm
J2: SWD; Connector_SWD_P2.54mm
J4: SH1106; Connector_SH1106_P2.54mm
R7, R8: 0; R_0805_2012Metric_Pad1.20x1.40mm_HandSolder
R11, R12, R25: 4,7k; R_0603_1608Metric_Pad0.98x0.95mm_HandSolder
R21, R32: 10k; R_0603_1608Metric_Pad0.98x0.95mm_HandSolder
R22: 5,1k; R_0603_1608Metric_Pad0.98x0.95mm_HandSolder
R24: 2k; R_0603_1608Metric_Pad0.98x0.95mm_HandSolder
R26: 2,7k; R_0603_1608Metric_Pad0.98x0.95mm_HandSolder
R30: 100k; R_0603_1608Metric_Pad0.98x0.95mm_HandSolder
SW2: Select; SW_Push_PB07_7x7mm
SW3: Start; SW_Push_PB07_7x7mm
SW4: Reset; SW_Push_SPST_China
TP10: NRST; TestPoint_THTPad_D2.0mm_Drill1.0mm

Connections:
+3,3V: J1.1, J2.1, J4.1, R11.2, R12.2, R21.2, R32.1, SW2.3 (C); also elsewhere on the board
+5V: C16.1, D6.4 (A); also elsewhere on the board
/BT_SELECT: R30.2; also elsewhere on the board
/BT_START: R22.1; also elsewhere on the board
/DISPLAY_SCL: J4.3, R12.1; also elsewhere on the board
/DISPLAY_SDA: J4.4, R11.1; also elsewhere on the board
/LED_B: R24.1; also elsewhere on the board
/LED_G: R25.1; also elsewhere on the board
/LED_R: R26.1; also elsewhere on the board
/NRST: C24.1, R32.2, SW4.2, TP10.1 (1_1); also elsewhere on the board
/SWCLK: J2.4; also elsewhere on the board
/SWDIO: J2.3; also elsewhere on the board
/UART_RX: R8.2; also elsewhere on the board
/UART_TX: R7.2; also elsewhere on the board
GNDD: C16.2, C17.2, C19.2, C24.2, J1.2, J2.2, J4.2, SW2.1 (A), SW3.4 (A), SW4.1; also elsewhere on the board
unnamed: D6.3 (BK), R24.2
unnamed: D6.2 (GK), R25.2
unnamed: D6.1 (RK), R26.2
unnamed: J1.3, R8.1
unnamed: J1.4, R7.1
unnamed: C17.1, R30.1, SW2.2 (B)
unnamed: C19.1, R21.1, R22.2, SW3.5 (B)

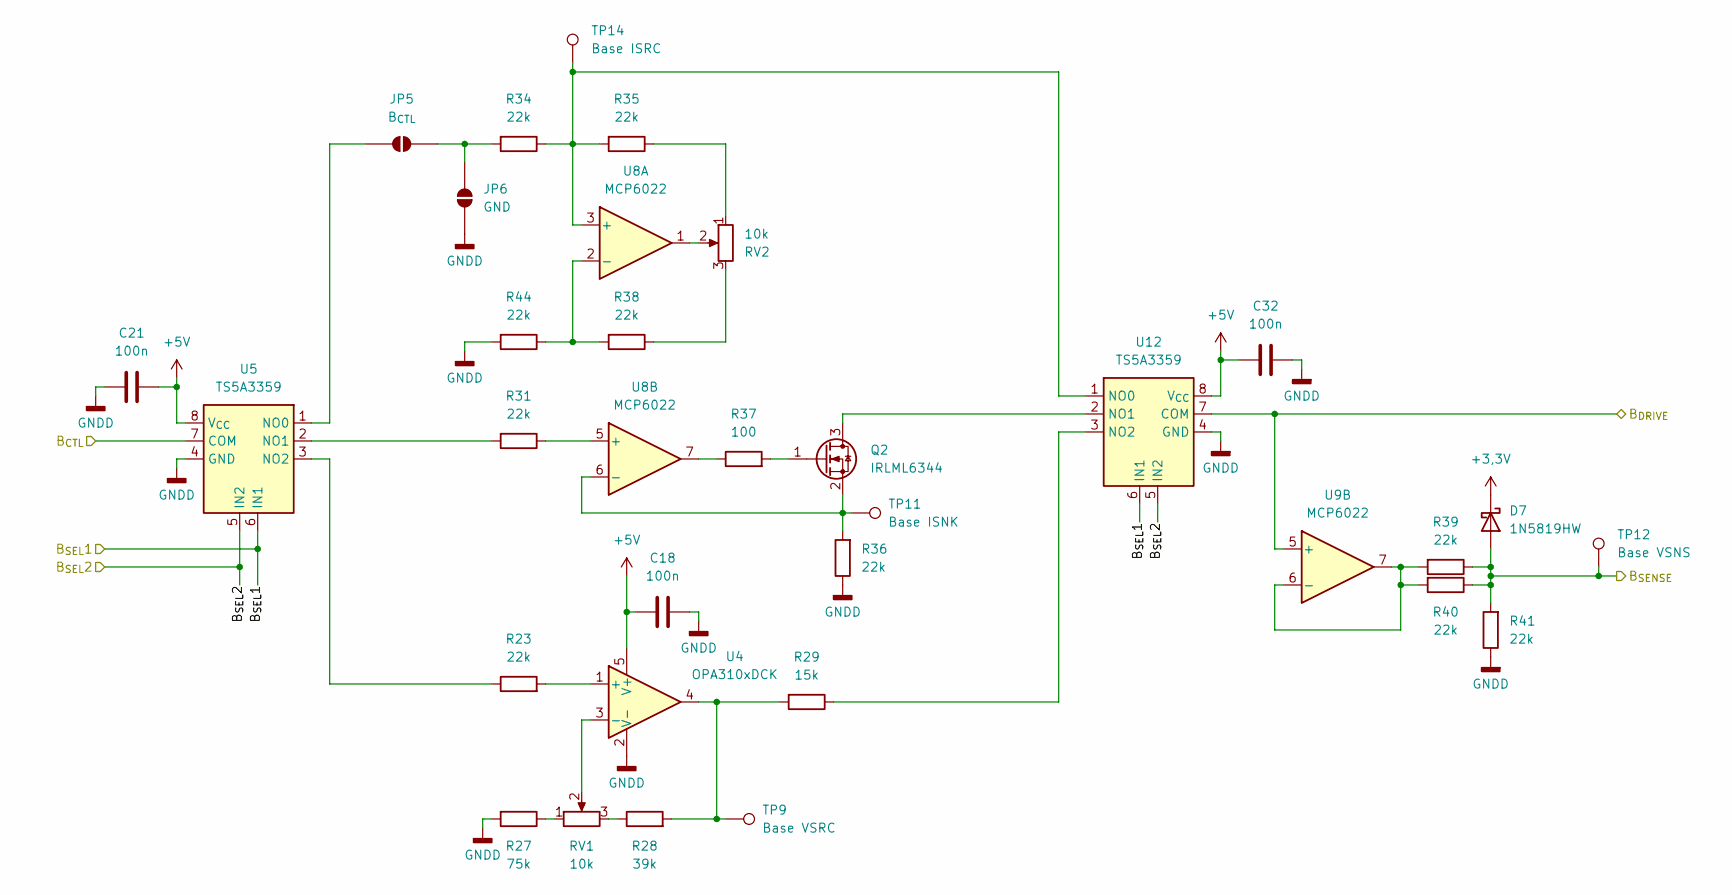
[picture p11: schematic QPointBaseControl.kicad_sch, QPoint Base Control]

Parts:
C18, C21, C32: 100n; C_0603_1608Metric_Pad1.08x0.95mm_HandSolder
D7: 1N5819HW; D_SOD-123_Handsoldering
JP5: B_{CTL}; SolderJumper-2_P1.3mm_Open_TrianglePad1.0x1.5mm
JP6: GND; SolderJumper-2_P1.3mm_Open_TrianglePad1.0x1.5mm
Q2: IRLML6344; SOT-23_Handsoldering
R23, R31, R34, R35, R36, R38, R39, R40, R41, R44: 22k; R_0603_1608Metric_Pad0.98x0.95mm_HandSolder
R27: 75k; R_0603_1608Metric_Pad0.98x0.95mm_HandSolder
R28: 39k; R_0603_1608Metric_Pad0.98x0.95mm_HandSolder
R29: 15k; R_0603_1608Metric_Pad0.98x0.95mm_HandSolder
R37: 100; R_0603_1608Metric_Pad0.98x0.95mm_HandSolder
RV1, RV2: 10k; Potentiometer_Bourns_3296X_Horizontal
TP9: Base VSRC; TestPoint_Pad_D2.0mm
TP11: Base ISNK; TestPoint_Pad_D2.0mm
TP12: Base VSNS; TestPoint_Pad_D2.0mm
TP14: Base ISRC; TestPoint_Pad_D2.0mm
U4: OPA310xDCK; SOT-353_SC-70-5_Handsoldering
U5, U12: TS5A3359; VSSOP-8_2.3x2mm_P0.5mm_Handsoldering
U8, U9: MCP6022; SOIC-8_3.9x4.9mm_P1.27mm_Handsoldering

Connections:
+3,3V: D7.1 (K); also elsewhere on the board
+5V: C18.1, C21.2, C32.2, U4.5 (V+), U5.8 (V_{CC}), U12.8 (V_{CC}); also elsewhere on the board
/BASE_ADC: D7.2 (A), R39.1, R40.1, R41.2, TP12.1 (1_1); also elsewhere on the board
/BASE_DAC: U5.7 (COM); also elsewhere on the board
/BASE_SEL1: U5.6 (IN1), U12.6 (IN1); also elsewhere on the board
/BASE_SEL2: U5.5 (IN2), U12.5 (IN2); also elsewhere on the board
/Base Control/B_{DRIVE}: U9.5 (+), U12.7 (COM); also elsewhere on the board
GNDD: C18.2, C21.1, C32.1, JP6.1 (A), R27.2, R36.1, R41.1, R44.2, U4.2 (V-), U5.4 (GND), U12.4 (GND); also elsewhere on the board
unnamed: JP5.1 (A), U5.1 (NO0)
unnamed: JP5.2 (B), JP6.2 (B), R34.2
unnamed: Q2.3 (D), U12.2 (NO1)
unnamed: Q2.1 (G), R37.2
unnamed: Q2.2 (S), R36.2, TP11.1 (1_1), U8.6 (-)
unnamed: R27.1, RV1.1
unnamed: R28.1, RV1.3
unnamed: R28.2, R29.2, TP9.1 (1_1), U4.4
unnamed: R35.1, RV2.1
unnamed: R37.1, U8.7
unnamed: R38.1, RV2.3
unnamed: RV2.2, U8.1
unnamed: R23.2, U4.1 (+)
unnamed: RV1.2, U4.3 (-)
unnamed: R31.2, U5.2 (NO1)
unnamed: R23.1, U5.3 (NO2)
unnamed: R38.2, R44.1, U8.2 (-)
unnamed: R31.1, U8.5 (+)
unnamed: R39.2, R40.2, U9.6 (-), U9.7
unnamed: R34.1, R35.2, TP14.1 (1_1), U8.3 (+), U12.1 (NO0)
unnamed: R29.1, U12.3 (NO2)

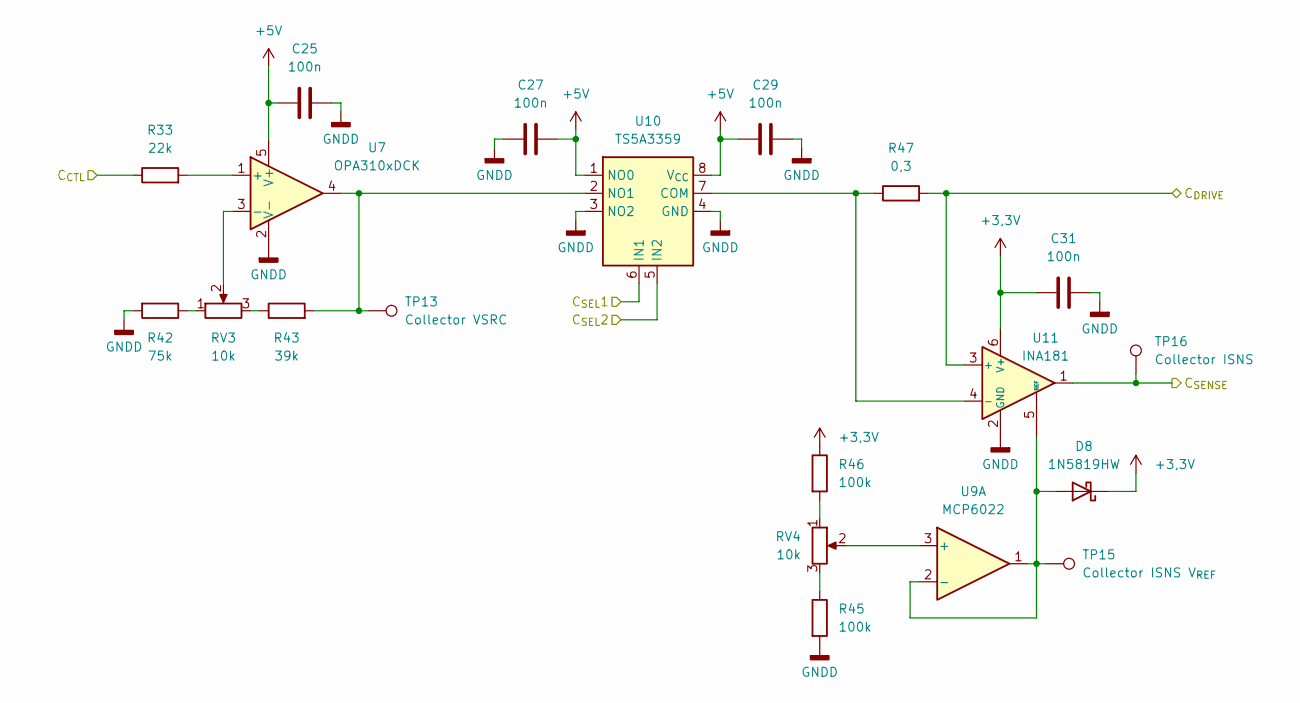
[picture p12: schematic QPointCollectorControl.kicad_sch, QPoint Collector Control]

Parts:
C25, C27, C29, C31: 100n; C_0603_1608Metric_Pad1.08x0.95mm_HandSolder
D8: 1N5819HW; D_SOD-123_Handsoldering
R33: 22k; R_0603_1608Metric_Pad0.98x0.95mm_HandSolder
R42: 75k; R_0603_1608Metric_Pad0.98x0.95mm_HandSolder
R43: 39k; R_0603_1608Metric_Pad0.98x0.95mm_HandSolder
R45, R46: 100k; R_0603_1608Metric_Pad0.98x0.95mm_HandSolder
R47: 0,3; R_0805_2012Metric_Pad1.20x1.40mm_HandSolder
RV3, RV4: 10k; Potentiometer_Bourns_3296X_Horizontal
TP13: Collector VSRC; TestPoint_Pad_D2.0mm
TP15: Collector ISNS V_{REF}; TestPoint_Pad_D2.0mm
TP16: Collector ISNS; TestPoint_Pad_D2.0mm
U7: OPA310xDCK; SOT-353_SC-70-5_Handsoldering
U9: MCP6022; SOIC-8_3.9x4.9mm_P1.27mm_Handsoldering
U10: TS5A3359; VSSOP-8_2.3x2mm_P0.5mm_Handsoldering
U11: INA181; SOT-23-6_Handsoldering

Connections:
+3,3V: C31.2, D8.1 (K), R46.1, U11.6 (V+); also elsewhere on the board
+5V: C25.1, C27.2, C29.2, U7.5 (V+), U10.1 (NO0), U10.8 (V_{CC}); also elsewhere on the board
/COLLECTOR_ADC: TP16.1 (1_1), U11.1; also elsewhere on the board
/COLLECTOR_DAC: R33.1; also elsewhere on the board
/COLLECTOR_SEL1: U10.6 (IN1); also elsewhere on the board
/COLLECTOR_SEL2: U10.5 (IN2); also elsewhere on the board
/Collector Control/C_{DRIVE}: R47.2, U11.3 (+); also elsewhere on the board
GNDD: C25.2, C27.1, C29.1, C31.1, R42.2, R45.2, U7.2 (V-), U10.3 (NO2), U10.4 (GND), U11.2 (GND); also elsewhere on the board
unnamed: D8.2 (A), TP15.1 (1_1), U9.1, U9.2 (-), U11.5 (REF)
unnamed: R42.1, RV3.1
unnamed: R43.1, RV3.3
unnamed: R45.1, RV4.3
unnamed: R46.2, RV4.1
unnamed: R33.2, U7.1 (+)
unnamed: RV3.2, U7.3 (-)
unnamed: RV4.2, U9.3 (+)
unnamed: R47.1, U10.7 (COM), U11.4 (-)
unnamed: R43.2, TP13.1 (1_1), U7.4, U10.2 (NO1)

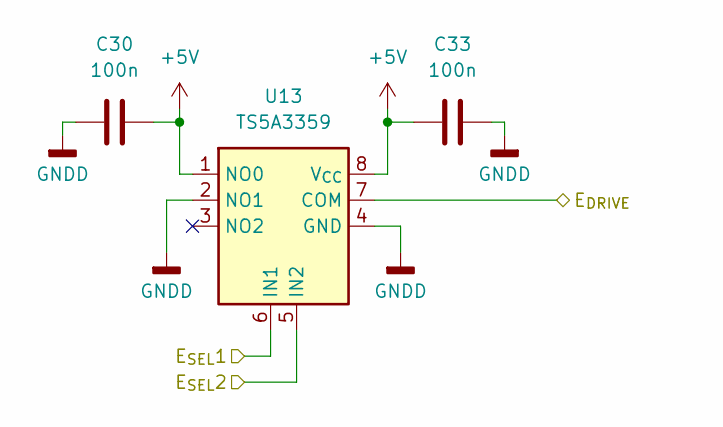
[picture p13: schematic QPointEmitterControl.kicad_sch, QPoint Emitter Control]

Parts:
C30, C33: 100n; C_0603_1608Metric_Pad1.08x0.95mm_HandSolder
U13: TS5A3359; VSSOP-8_2.3x2mm_P0.5mm_Handsoldering

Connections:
+5V: C30.2, C33.2, U13.1 (NO0), U13.8 (V_{CC}); also elsewhere on the board
/EMITTER_SEL1: U13.6 (IN1); also elsewhere on the board
/EMITTER_SEL2: U13.5 (IN2); also elsewhere on the board
/Emitter Control/E_{DRIVE}: U13.7 (COM); also elsewhere on the board
GNDD: C30.1, C33.1, U13.2 (NO1), U13.4 (GND); also elsewhere on the board

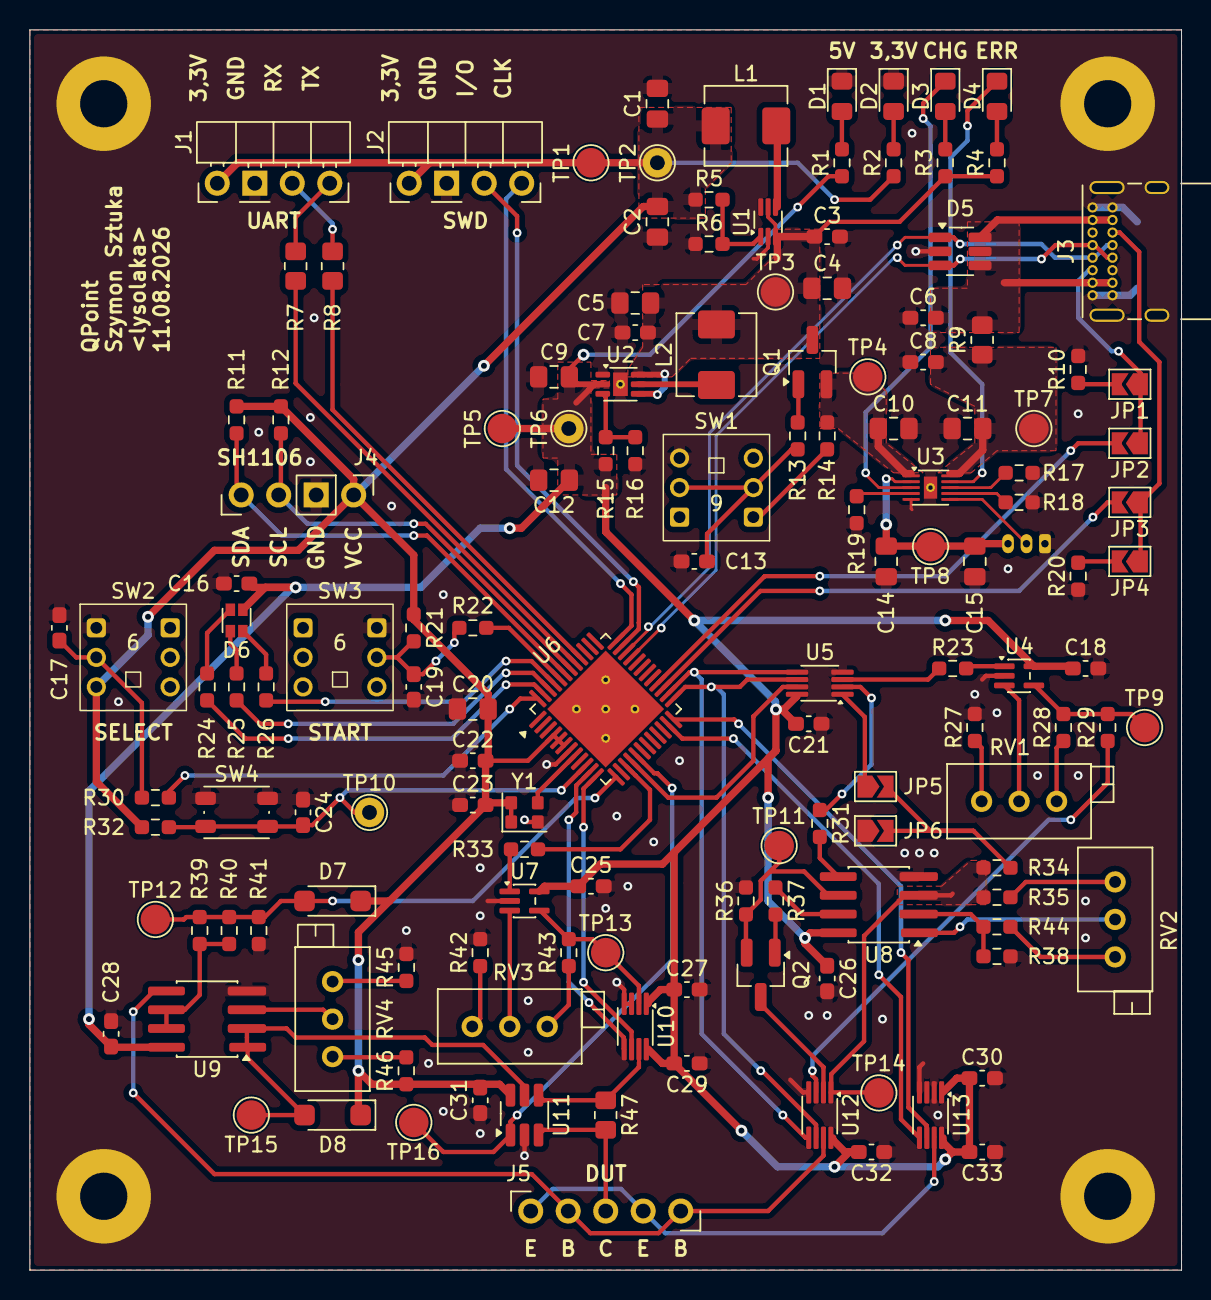
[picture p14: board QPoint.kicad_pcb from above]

Board: 2 copper layers, 78.0 x 84.0 mm, 146 parts (1 on the bottom side), 97 nets.

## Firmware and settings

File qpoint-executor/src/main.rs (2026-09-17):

use iced::Element;
use iced::widget::{button, checkbox, column, pick_list, radio, row, space, text, text_input};
use iced::{Alignment, Length, Size};

use native_dialog::{DialogBuilder, MessageLevel};

use qpoint_common::measurement::{BaseSource, CollectorSource, EmitterSource};
use qpoint_common::{Command, Parameter};

mod serial;

fn main() -> iced::Result {
    iced::application(State::default, State::update, State::view)
        .window(iced::window::Settings {
            size: Size::new(550.0, 550.0),
            ..Default::default()
        })
        .title("QPoint Executor")
        .run()
}

#[derive(thiserror::Error, Debug)]
enum Error {
    #[error("{0}")]
    SerialPort(#[from] serialport::Error),
    #[error("{0}")]
    Serialization(#[from] postcard::Error),
    #[error("{0}")]
    Io(#[from] std::io::Error),
    #[error("{0}")]
    ParseFloat(#[from] std::num::ParseFloatError),
    #[error("{0}")]
    ParseInt(#[from] std::num::ParseIntError),
    #[error("The device is not found")]
    NotFound,
}

#[derive(Debug, Clone, Copy, PartialEq, Eq)]
enum CommandFlat {
    Attach,
    Detach,
    DisplayParam,
    LedSet,
    BaseSelect,
    BaseSet,
    CollectorSelect,
    CollectorSet,
    EmitterSelect,
}

impl CommandFlat {
    fn into_command(&self, values: &State) -> Result<Command, crate::Error> {
        let cmd = match self {
            CommandFlat::Attach => Command::Attach,
            CommandFlat::Detach => Command::Detach,
            CommandFlat::DisplayParam => Command::DisplayParam {
                param: values.param,
                value: values.param_value.parse()?,
            },
            CommandFlat::LedSet => Command::LedSet(
                u8::from_str_radix(&values.led_r, 16)?,
                u8::from_str_radix(&values.led_g, 16)?,
                u8::from_str_radix(&values.led_b, 16)?,
            ),
            CommandFlat::BaseSelect => Command::BaseSelect(values.base_source.expect("never None")),
            CommandFlat::BaseSet => {
                let value = values.base_value.parse()?;
                Command::BaseSet {
                    value,
                    measure: values.base_measure,
                }
            }
            CommandFlat::CollectorSelect => {
                Command::CollectorSelect(values.collector_source.expect("never None"))
            }
            CommandFlat::CollectorSet => {
                let value = values.collector_value.parse()?;
                Command::CollectorSet {
                    value,
                    measure: values.collector_measure,
                }
            }
            CommandFlat::EmitterSelect => {
                Command::EmitterSelect(values.emitter_source.expect("never None"))
            }
        };

        Ok(cmd)
    }
}

#[derive(Debug, Clone)]
enum Message {
    ExecutePressed,
    CommandSelected(CommandFlat),
    ParamSelected(Parameter),
    ParamValueChanged(String),
    LedRChanged(String),
    LedGChanged(String),
    LedBChanged(String),
    BaseSourceSelected(BaseSource),
    BaseValueChanged(String),
    BaseMeasureToggled(bool),
    CollectorSourceSelected(CollectorSource),
    CollectorValueChanged(String),
    CollectorMeasureToggled(bool),
    EmitterSourceSelected(EmitterSource),
}

struct State {
    param: Parameter,
    param_value: String,
    led_r: String,
    led_g: String,
    led_b: String,
    base_source: Option<BaseSource>,
    base_value: String,
    base_measure: bool,
    collector_source: Option<CollectorSource>,
    collector_value: String,
    collector_measure: bool,
    emitter_source: Option<EmitterSource>,
    selected_command: CommandFlat,
}

impl State {
    fn update(&mut self, message: Message) {
        match message {
            Message::ExecutePressed => {
                if let Err(e) = self
                    .selected_command
                    .into_command(&self)
                    .inspect(|c| eprintln!("Executing: {:?}", c))
                    .map(|c| serial::execute(c))
                    .flatten()
                    .inspect(|r| eprintln!("Response: {:?}", r))
                {
                    DialogBuilder::message()
                        .set_level(MessageLevel::Error)
                        .set_title("QPoint Executor")
                        .set_text(format!("Error: {}", e))
                        .alert()
                        .show()
                        .unwrap();
                }
            }
            Message::CommandSelected(command) => self.selected_command = command,
            Message::ParamValueChanged(value) => self.param_value = value,
            Message::ParamSelected(param) => self.param = param,
            Message::LedRChanged(r) => self.led_r = r,
            Message::LedGChanged(g) => self.led_g = g,
            Message::LedBChanged(b) => self.led_b = b,
            Message::BaseSourceSelected(base_source) => self.base_source = Some(base_source),
            Message::BaseValueChanged(v) => self.base_value = v,
            Message::BaseMeasureToggled(base_measure) => self.base_measure = base_measure,
            Message::CollectorSourceSelected(collector_source) => {
                self.collector_source = Some(collector_source)
            }
            Message::CollectorValueChanged(v) => self.collector_value = v,
            Message::CollectorMeasureToggled(collector_measure) => {
                self.collector_measure = collector_measure
            }
            Message::EmitterSourceSelected(emitter_source) => {
                self.emitter_source = Some(emitter_source)
            }
        }
    }

    fn view(&self) -> Element<'_, Message> {
        let radio_attach = radio(
            "Attach",
            CommandFlat::Attach,
            Some(self.selected_command),
            Message::CommandSelected,
        );

        let radio_detach = radio(
            "Detach",
            CommandFlat::Detach,
            Some(self.selected_command),
            Message::CommandSelected,
        );

        let radio_display_param = radio(
            "Display parameter",
            CommandFlat::DisplayParam,
            Some(self.selected_command),
            Message::CommandSelected,
        );

        let radio_led_set = radio(
            "LED set",
            CommandFlat::LedSet,
            Some(self.selected_command),
            Message::CommandSelected,
        );

        let radio_base_select = radio(
            "Base select",
            CommandFlat::BaseSelect,
            Some(self.selected_command),
            Message::CommandSelected,
        );

        let radio_base_set = radio(
            "Base set",
            CommandFlat::BaseSet,
            Some(self.selected_command),
            Message::CommandSelected,
        );

        let radio_collector_select = radio(
            "Collector select",
            CommandFlat::CollectorSelect,
            Some(self.selected_command),
            Message::CommandSelected,
        );

        let radio_collector_set = radio(
            "Collector set",
            CommandFlat::CollectorSet,
            Some(self.selected_command),
            Message::CommandSelected,
        );

        let radio_emitter_select = radio(
            "Emitter select",
            CommandFlat::EmitterSelect,
            Some(self.selected_command),
            Message::CommandSelected,
        );

        let display_param = row![
            radio_display_param,
            space().width(6),
            pick_list(
                [
                    Parameter::Hie,
                    Parameter::Hre,
                    Parameter::Hfe,
                    Parameter::Hoe
                ],
                Some(self.param),
                Message::ParamSelected
            ),
            text("Value:"),
            text_input("value", &self.param_value)
                .on_input(Message::ParamValueChanged)
                .width(Length::Fixed(140.0)),
        ]
        .spacing(12)
        .align_y(Alignment::Center);

        let led_set = row![
            radio_led_set,
            space().width(88),
            text("R:"),
            text_input("R", &self.led_r)
                .on_input(Message::LedRChanged)
                .width(Length::Fixed(48.0)),
            text("G:"),
            text_input("G", &self.led_g)
                .on_input(Message::LedGChanged)
                .width(Length::Fixed(48.0)),
            text("B:"),
            text_input("B", &self.led_b)
                .on_input(Message::LedBChanged)
                .width(Length::Fixed(48.0))
        ]
        .spacing(12)
        .align_y(Alignment::Center);

        let base_select = row![
            radio_base_select,
            space().width(61),
            pick_list(
                [
                    BaseSource::HighZ,
                    BaseSource::ISource,
                    BaseSource::ISink,
                    BaseSource::VSource,
                ],
                self.base_source,
                Message::BaseSourceSelected,
            )
        ]
        .spacing(12)
        .align_y(Alignment::Center);

        let base_set = row![
            radio_base_set,
            space().width(83),
            text("Value:"),
            text_input("value", &self.base_value)
                .on_input(Message::BaseValueChanged)
                .width(Length::Fixed(140.0)),
            checkbox(self.base_measure)
                .label("Measure")
                .on_toggle(Message::BaseMeasureToggled),
        ]
        .spacing(12)
        .align_y(Alignment::Center);

        let collector_select = row![
            radio_collector_select,
            space().width(31),
            pick_list(
                [
                    CollectorSource::HighZ,
                    CollectorSource::VCC,
                    CollectorSource::VSource,
                    CollectorSource::GND,
                ],
                self.collector_source,
                Message::CollectorSourceSelected,
            )
        ]
        .spacing(12)
        .align_y(Alignment::Center);

        let collector_set = row![
            radio_collector_set,
            space().width(52),
            text("Value:"),
            text_input("value", &self.collector_value)
                .on_input(Message::CollectorValueChanged)
                .width(Length::Fixed(140.0)),
            checkbox(self.collector_measure)
                .label("Measure")
                .on_toggle(Message::CollectorMeasureToggled),
        ]
        .spacing(12)
        .align_y(Alignment::Center);

        let emitter_select = row![
            radio_emitter_select,
            space().width(42),
            pick_list(
                [EmitterSource::HighZ, EmitterSource::VCC, EmitterSource::GND],
                self.emitter_source,
                Message::EmitterSourceSelected,
            )
        ]
        .spacing(12)
        .align_y(Alignment::Center);

        let execute_button = button(
            text("Execute")
                .align_x(Alignment::Center)
                .width(Length::Fill),
        )
        .on_press(Message::ExecutePressed)
        .width(Length::Fill)
        .padding([8, 24]);

        column![
            text("QPoint Command Executor")
                .size(24)
                .align_x(Alignment::Center)
                .width(Length::Fill),
            space().height(12),
            radio_attach,
            space().height(3),
            radio_detach,
            space().height(3),
            display_param,
            space().height(3),
            led_set,
            space().height(8),
            base_select,
            base_set,
            space().height(8),
            collector_select,
            collector_set,
            space().height(8),
            emitter_select,
            space().height(16),
            execute_button,
        ]
        .width(Length::Fill)
        .padding(20)
        .spacing(6)
        .align_x(Alignment::Start)
        .into()
    }
}

impl Default for State {
    fn default() -> Self {
        Self {
            param: Parameter::Hie,
            param_value: "0".to_string(),
            led_r: "0".to_string(),
            led_g: "0".to_string(),
            led_b: "0".to_string(),
            base_source: Some(BaseSource::HighZ),
            base_value: "0".to_string(),
            base_measure: false,
            collector_source: Some(CollectorSource::HighZ),
            collector_value: "0".to_string(),
            collector_measure: false,
            emitter_source: Some(EmitterSource::HighZ),
            selected_command: CommandFlat::Attach,
        }
    }
}

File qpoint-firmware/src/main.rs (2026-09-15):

#![no_std]
#![no_main]

use defmt_rtt as _;
use panic_probe as _;

use embassy_executor::Spawner;

use embassy_stm32::{Peri, peripherals};
use embassy_stm32::{dma, exti, i2c, usb};

mod communication;
mod config;
mod display;
mod led;
mod measurement;
mod ui;
pub mod util;

use crate::util::color;
use crate::util::sync::RGB_LED_S;

assign_resources::assign_resources! {
    display: DisplayResources {
        i2c: I2C2,
        tx_dma: DMA1_CH2,
        rx_dma: DMA1_CH3,
        scl: PB3,
        sda: PB4,
    },
    led: LedResources {
        r: PB6,
        g: PB7,
        b: PB8,
        tim: TIM4,
    },
    measurement: MeasurementResources {
        dac: DAC1,
        adc: ADC1,
        dma: DMA1_CH1,
        base_sel1: PB13,
        base_sel2: PB14,
        base_dac: PA5,
        base_adc: PA2,
        collector_sel1: PA1,
        collector_sel2: PA0,
        collector_dac: PA4,
        collector_adc: PA6,
        emitter_sel1: PB12,
        emitter_sel2: PB11,
    },
    ui: UiResources {
        start_pin: PB5,
        start_exti: EXTI5,
        select_pin: PB9,
        select_exti: EXTI9,
    }
    usb: UsbResources {
        usb: USB,
        dp: PA12,
        dm: PA11,
    }
}

embassy_stm32::bind_interrupts!(struct Interrupts {
    DMA1_CHANNEL1 => dma::InterruptHandler<peripherals::DMA1_CH1>;
    DMA1_CHANNEL2_3 => dma::InterruptHandler<peripherals::DMA1_CH2>, dma::InterruptHandler<peripherals::DMA1_CH3>;
    EXTI4_15 => exti::InterruptHandler<embassy_stm32::interrupt::typelevel::EXTI4_15>;
    I2C2_3 => i2c::EventInterruptHandler<peripherals::I2C2>, i2c::ErrorInterruptHandler<peripherals::I2C2>;
    USB_UCPD1_2 => usb::InterruptHandler<peripherals::USB>;
});

#[embassy_executor::main]
async fn main(spawner: Spawner) {
    let p = embassy_stm32::init(config::hal_config());
    let r = split_resources!(p);

    defmt::info!("Startup: OK!");
    defmt::debug!("Spawning tasks...");

    spawner.spawn(defmt::unwrap!(led::driver(r.led)));
    spawner.spawn(defmt::unwrap!(ui::driver(r.ui)));
    spawner.spawn(defmt::unwrap!(display::driver(r.display)));
    spawner.spawn(defmt::unwrap!(measurement::runner(r.measurement)));

    communication::start(spawner, r.usb);

    RGB_LED_S.signal(color::OK);

    defmt::info!("Tasks spawned: OK!");
    defmt::debug!("Yeilding to the executor...");
}

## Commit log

2026-08-27 feat: upload PCB project files
    [QPoint.kicad_pcb, QPoint.kicad_sch, QPointBaseControl.kicad_sch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]
2026-09-08 feat: implement a helper for ADC measurements
2026-09-09 perf: improve DAC value calculation for voltage sources
2026-09-09 fix: await the ADC read future for measurements
    [adc_control.rs]
2026-09-09 fix: set the DAC value to 0 before switching the collector source
2026-09-10 feat: implement an RGB LED driver
2026-09-11 feat: use LED colours throughout the program
2026-09-12 feat: add an error message for the float parsing error
    [main.rs]
2026-09-12 feat: implement remote RGB LED control
2026-09-12 feat: implement a driver for the local UI
2026-09-16 feat: implement display driver update logic
2026-09-17 fix: flip the sign of current on the collector
    [adc_control.rs]
2026-09-17 fix: adjust the window size
    [main.rs]
2026-10-13 feat: use radio buttons for transistor type selection
2026-10-20 feat: implement communication with the board
2026-10-22 feat: lock the start button during measurement
2026-10-24 fix: rework `PlotData` to account for non-constant X-axis
